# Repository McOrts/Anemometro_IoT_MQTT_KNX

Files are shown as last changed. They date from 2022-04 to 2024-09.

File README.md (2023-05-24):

# Conectividad IoT para anemómetros
Cada día es más habitual el uso de sensores de viento integrados con la lógica domótica de los edificios. Para ello es imprescindible considerar el anemómetro como un dispositivo IoT con capacidad de conexión en los diferentes protocolos de comunicación: MQTT, KNX, y LoRaWAN medios de transmisión de modulación inalámbrica como LoRA e WiFi o cableada con Ethernet con TCP/IP.

## Versión Arduino WEMOS-D1 MQTT por WiFi
Esta es la versión más simple y versátil. El sensor está conectado a un microcontrolador ESP8266 montado en una caja estanca con resistencia IP66 por lo que puede instalarse en el exterior. Además podrá utilizarse como dispositivo portátil.

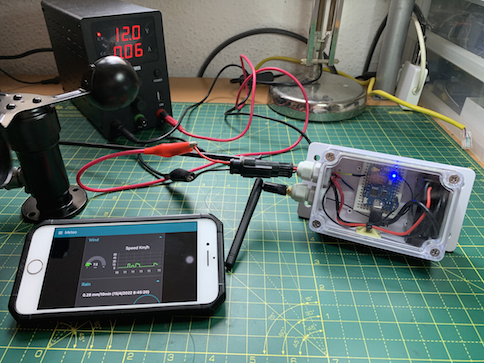
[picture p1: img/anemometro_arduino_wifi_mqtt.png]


### Lista de materiales
- [Anemómetro de cazoletas SKU:SEN0170](https://www.dfrobot.com/search-SEN0170.html)
- [WEMOS D1 Mini Pro 4M](https://es.aliexpress.com/item/32801063577.html)
- [Adaptador de corriente 12V a micro-USB](https://es.aliexpress.com/item/32973455778.html)
- [Caja exterior resistencia IP66 tapa transparente](https://es.aliexpress.com/item/4000200361035.html)

### Montaje
Utilizando cualquier protoboard solo se requiere conectar la masa comùn del microcontrolador y el anemómetro y la senal de tensión de salida del mismo a la entrada analógica del Wemos (ESP8266)

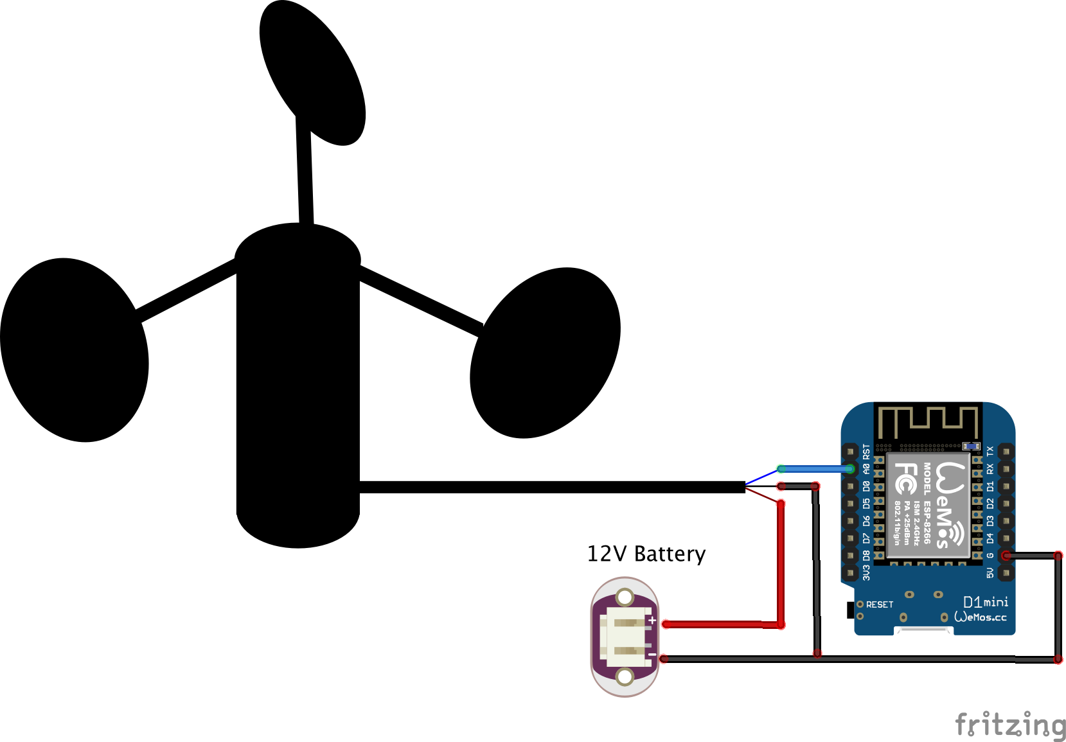
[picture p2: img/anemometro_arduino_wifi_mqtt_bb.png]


### Software
Partimos de que se dispone de un broker MQTT tipo Mosquitto y un Node-RED para procesar la información. El firmware utiliza la librería para WiFi (ESP8266WiFi.h) y la de MQTT (PubSubClient.h).
Como se ha utilizado un anemómetro alimentado por 12V que traduce la velocidad del viento a una tensión de salida entre los 0.17V para una velocidad de 1m/s a 5V para 30 m/s. El programa del microcontrolador hará este cálculo de manera que el mensaJe MQTT contiene unicamente la velocidad del viento.
Además el programa, cuando hay viento, enciende el led de la placa WEMOS Apagándolo cuando es igual a cero.

```cpp
#include <ESP8266WiFi.h>
#include <PubSubClient.h>
#include "settings.h"

unsigned long int temp1;

/* Configuración sensor */
unsigned int WindSpeed ;              

/* Configuración cliente WiFi */
WiFiClient espClient;

/* Configuración MQTT */
PubSubClient clientMqtt(espClient);
char msg[50];
String mqttcommand = String(14);

void setup() {
  Serial.begin(9600);

  // Inicializa el LED de la placa
  pinMode(LED_BUILTIN, OUTPUT);
  digitalWrite(LED_BUILTIN, HIGH);
  delay(500);

  /* Iniciar wifi */
  setup_wifi();
  clientMqtt.setServer(mqtt_server, mqtt_port);
  clientMqtt.setCallback(callback);
}

void setup_wifi() {
  delay(10);

  // Comienza el proceso de conexión a la red WiFi
  Serial.println();
  Serial.print("[WIFI]Conectando a ");
  Serial.println(ssid);

  // Modo estación
  WiFi.mode(WIFI_STA);
  // Inicio WiFi
  WiFi.begin(ssid, password);

  while (WiFi.status() != WL_CONNECTED) {
    delay(500);
    Serial.print(".");
  }

  Serial.println("");
  Serial.println("[WIFI]WiFi conectada");
  Serial.print("[WIFI]IP: ");
  Serial.print(WiFi.localIP());
  Serial.println("");
}

void callback(char* topic, byte* payload, unsigned int length) {
  Serial.print("[MQTT]Mensaje recibido (");
  Serial.print(topic);
  Serial.print(") ");
  mqttcommand = "";
  for (int i = 0; i < length; i++) {
    mqttcommand += (char)payload[i];
  }
  Serial.print(mqttcommand);
  Serial.println();
  // Switch on the LED if an 1 was received as first character
  if (mqttcommand == "comando") {
    Serial.println("comando");
  }  
}

void reconnect() {
  Serial.print("[MQTT]Intentando conectar a servidor MQTT... ");
  // Bucle hasta conseguir conexión
  while (!clientMqtt.connected()) {
    Serial.print(".");
    // Intento de conexión
    if (clientMqtt.connect(mqtt_id)) { // Ojo, para más de un dispositivo cambiar el nombre para evitar conflicto
      Serial.println("");
      Serial.println("[MQTT]Conectado al servidor MQTT");
      // Once connected, publish an announcement...
      clientMqtt.publish(mqtt_sub_topic_healthcheck, "starting");
      // ... and subscribe
      clientMqtt.subscribe(mqtt_sub_topic_operation);
    } else {
      Serial.print("[MQTT]Error, rc=");
      Serial.print(clientMqtt.state());
      Serial.println("[MQTT]Intentando conexión en 5 segundos");

      delay(5000);
    }
  }
}

void loop() {
  if (!clientMqtt.connected()) {
    reconnect();
  }
  clientMqtt.loop();
    
  if (millis()-temp1>update_time_sensors) {
    temp1=millis();
    
    // Lectura del puerto analógico y traducción del voltaje a velocidad  
    WindSpeed = 6 * analogRead(A0) * (5.0 / 1023.0);

    Serial.print("Velocidad del viento: ");
    Serial.print(WindSpeed);
    Serial.println(" m/s");
      
    // Envía la lectura por MQTT
    snprintf (msg, 10, "%6i", WindSpeed);
    Serial.print("[MQTT] Sending data: ");
    Serial.println(msg);
    clientMqtt.publish(mqtt_pub_topic_voltage, msg);   
    delay (1000);
    if (WindSpeed==0) {
      digitalWrite(LED_BUILTIN, HIGH);       
    } else {
      digitalWrite(LED_BUILTIN, LOW);
    }
  }
}
```
Los parámetros de conexión y tiempos, están definidos en un setting.h:

```cpp
// WiFi Configuration
const char* ssid = "MiFibra-2D79-terraza";
const char* password = "";

// MQTT Configuration
const char* mqtt_server = "192.168.1.114";
const int mqtt_port = 1883;
const char* mqtt_id = "anemometer_cups";
const char* mqtt_sub_topic_healthcheck = "/home/meteo/anemometer/healthcheck";
const char* mqtt_pub_topic_voltage = "/home/meteo/anemometer/wind_speed";
const char* mqtt_sub_topic_operation = "/home/meteo/anemometer/operation";

// Other params
const int update_time_sensors = 59000;
```

### Back-end
El procesado y almacenamiento de la información se orquesta desde una aplicación Node-RED. El _flow_ está subscrito al _topic_ de velocidad de viento "/home/meteo/anemometer/wind_speed". A partir del mensaje con la velocidad de viento en m/s, se hace el cálculo a km/h para almacenar el dato en una BBDD MySQL, presentar la información en un _dashboard_ y validar el umbral de alerta para enviar un mensaje por el servicio IFTTT. El código .json del flujo está en: https://github.com/McOrts/Anemometro_IoT_MQTT_KNX/blob/main/code/node-red_flow.json



## Versión RaspberryPi MQTT por Ethernet
También se puede implementar un sensor de viento sobre una _single board computer_ como la Raspberry Pi y utilizando señal de pulsos como la que tiene anemómetros como el [WH-SP-WS01](https://es.aliexpress.com/item/1005001484228267.html)

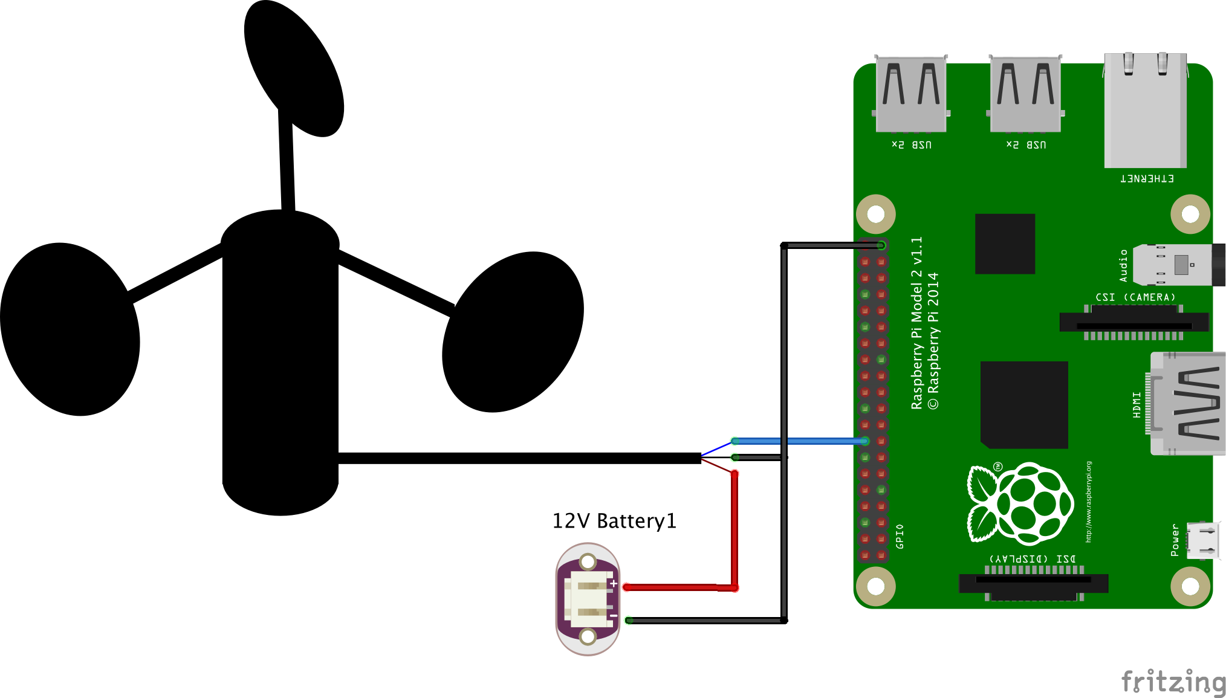
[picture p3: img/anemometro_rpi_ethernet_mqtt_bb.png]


### Sofware
En este caso he empleado un programa Python que además de enviar el mensaje MQTT, almacena la lectura en una BBDD MySQL y notifica por mail si la velocidad del viento excede de un umbral. Este y otro parámetros están configurados externamente en el fichero config.json.

```python
#!/usr/bin/python
# -*- coding: utf-8 -*-

import RPi.GPIO as GPIO
import smtplib
import datetime
import time
import MySQLdb as mdb
import logging
import os
import fnmatch
import math
import json
from pprint import pprint
import sys
import paho.mqtt.client as mqtt

# To avoid the error on rc.local execution envirotment: 
#WARNING urllib3.connectionpool Retrying (Retry(total=2, connect=None, read=None, redirect=None, status=None)) after connection broken by 'NewConnectionError('<urllib3.connection
logging.getLogger("urllib3").setLevel(logging.ERROR)

# Then the code sets up the logging module. We are going to use the basicConfig() function to set up the default handler 
# so that any debug messages are written to the file /home/pi/event_error.log.
logging.basicConfig(filename='/home/pi/wind_event_error.log',
  level=logging.DEBUG,
  format='%(asctime)s %(levelname)s %(name)s %(message)s')
logger=logging.getLogger(__name__)

# Read the configuration file
DEFAULT_CONFIG_PATH = '/home/pi/config.json'
with open(DEFAULT_CONFIG_PATH, 'r') as config_file:
  config = json.load(config_file)

# anemometer parameters
count = 0
radius = 9.0
comp_factor = 2.3
interval = 60
speed = 0

# Function for storing readings into MySQL
def insertDB(speed):
  try:
    con = mdb.connect(config['db_server_ip'],
                      config['db_update_user'],
                      config['db_update_password'],
                      'measurements');
    cursor = con.cursor()
    sql = "INSERT INTO wind(speed) VALUES ('%s')" % (speed)
    cursor.execute(sql)
    sql = []
    con.commit()
    con.close()
  except mdb.Error as e:
    logger.error(e)

# Function for send an email notifing the speed reach the maximum 
def send_email_wind_speed(speed):
    # Specifying the from and to addresses
    toaddr = config['mail']['toaddr']
    cc = config['mail']['cc']
    fromaddr = config['mail']['fromaddr']
    message_subject = "[WIND] Home wind speed alert"
    message_text = "The wind speed is (Km/h): %s" % speed
    message = "From: %s\r\n" % fromaddr + "To: %s\r\n" % toaddr + "Subject: %s\r\n" % message_subject + "\r\n"  + message_text
    toaddrs = [toaddr] 
    username = '¿?@gmail.com'
    password = '¿?'
    # Sending the mail  
    try:
      server = smtplib.SMTP_SSL("smtp.gmail.com", 465)
      server.ehlo()
      server.login(config['mail']['username'],config['mail']['password'])
      # ssl server doesn't support or need tls, so don't call server.starttls() 
      server.sendmail(fromaddr, toaddrs, message)
      server.close()
    except:
      print ("failed to send mail")

# Function for calculate wind speed
def calculate_speed(r_cm, factor, time_sec):
    global count
    circ_cm = (2 * math.pi) * r_cm
    rot = count / 2.0
    dist_km = (circ_cm * rot) / 100000.0 # convert to kilometres
    km_per_sec = dist_km / time_sec
    km_per_hour = km_per_sec * 3600 # convert to distance per hour
    km_per_hour = km_per_hour * factor
    km_per_hour = round(km_per_hour,2)
    return km_per_hour

def spin(channel):
    global count
    count += 1

# Function for publish MQTT messages
def publish_MQTT_messages (p_event):
  try:
    client = mqtt.Client()
    # compose the message 
    topic = config['domohome_wind']['topic']
    payload = '{:3.2f}'.format(p_event / 1.)
    client.connect(config['MQTT']['broker_server_ip'],1883,60)
    client.publish (topic, payload)

    client.disconnect();
  except Exception as e:
    print ("exception")
    logger.error("Exception MQTT sending message: %s\n"+" "+e.__str__())

GPIO.setmode(GPIO.BCM)
GPIO.setup(config['domohome_wind']['gpio_pin'], GPIO.IN, GPIO.PUD_UP)
GPIO.add_event_detect(config['domohome_wind']['gpio_pin'], GPIO.FALLING, callback=spin)

while True:
    count = 0
    time.sleep(interval)
    speed = calculate_speed(radius, comp_factor, interval)
#    insertDB (speed)
    publish_MQTT_messages(speed)
    if speed > config['domohome_wind']['max_warning']:
        send_email_wind_speed(speed) 
```

## Versión Arduino UNO KNX
Otra opción más compleja es la integrar el sensor de viento en un bus KNX. Para asegurar la compatibilidad he usado un Arduino Uno original. El modo de lectura del anemómetro es idéntico al utilizado en el WEMOS D1. Pero la transmisión del mensaje se hace a través de comandos enviados por el puerto serie del Arduino.
A su vez necesitamos traducir estas señales a modo TTL y formato RS323 que es la manera en la que podremos insertar el mensaje en el bus KNX utilizando el gateway SKX-Open de Zennio. 

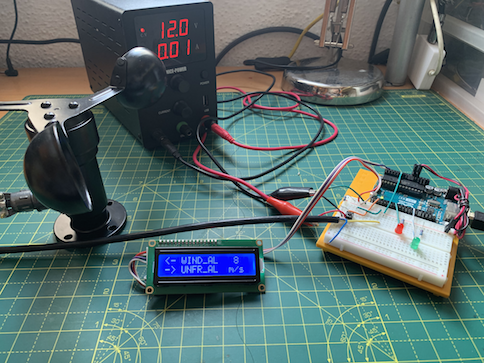
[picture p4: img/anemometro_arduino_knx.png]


### Hardware
Para este montaje, además del anemómetro de referencia utilizado [SKU:SEN0170](https://www.dfrobot.com/search-SEN0170.html), y un Arduino Uno. Para poder llevar el mensaje al bus NKX necesitamos dos componentes:
- [Módulo convertidor de puerto serie MAX3232 RS232 a TTL](https://es.aliexpress.com/item/32982290904.html)
- [Interface Bus KNX a RS232](https://www.zennio.com/products/interfaces/skx-open)

### Montaje

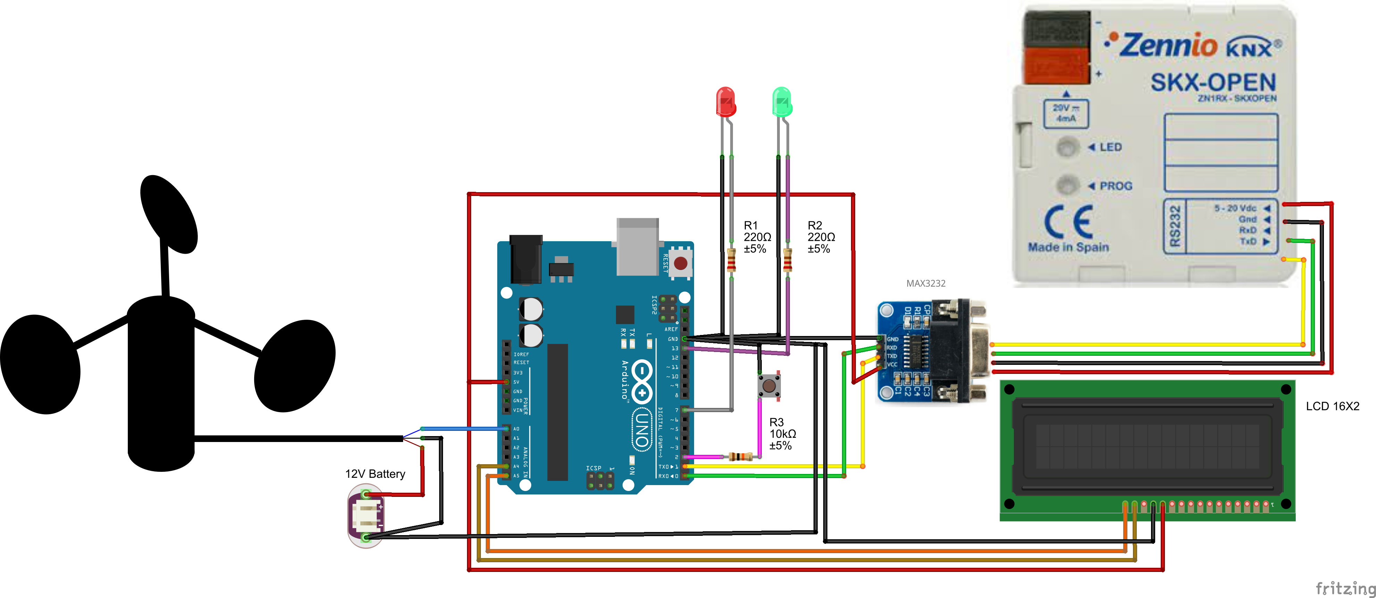
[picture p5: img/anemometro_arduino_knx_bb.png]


### Sofware
En este caso tenemos un sketch de arduino con una lógica más compleja para construir un diálogo a fin de interactuar con los otros elementos de la red KNX como persianas y botoneras.

```cpp
/* Diálogo:
Estado incial: leds apagados y no lee el sensor.
Cuando se pulsa el botón  
(1) Se empieza a leer el sensor cada 2 segundos
  * Si el valor < 800
    * Se envia "NOAL"
  * si el valor >=4 m/s
    * Se envía "WIND_AL" 
    * Se conmuta el LED del verde al rojo
    * Deja de leer el sensor
    * Se espera a recibir un "CLOSED_S" que indica que la persiana está cerrada
    * Se apaga el led rojo
    * Se espera a recibir un "UNFROZEN_AL" indica desbloqueo del usuario desde la botonera KNX
    * Se espera un segundo y
       * Se envia un "UNFR"
       * Se reestablece el estado al punto (1)
*/
#include <Wire.h> 
#include <LiquidCrystal_I2C.h>

#define sensor A0 
#define boton 2 
#define ledrojo 7
#define ledverde 12

const int sensorvalue = 4;

bool leyendo;
unsigned long int temps1;
String incomingString;

//Creamos el objeto lcd con la dirección 0x3F, 16 columnas y 2 filas
LiquidCrystal_I2C lcd(0x3F,16,2);  

void setup() {
  Serial.begin(9600);
  pinMode (sensor, INPUT);
  pinMode (boton, INPUT);
  pinMode (ledrojo, OUTPUT);
  pinMode (ledverde, OUTPUT);
  temps1=millis();
  leyendo = false;
  // Inicializamos la pantalla LCD
  lcd.init();
  lcd.backlight();
  lcd.setCursor(0, 0);
  lcd.print("<-");
  lcd.setCursor(0, 1);
  lcd.print("->          m/s");
}

void analizar_sensor(){
  if (millis()-temps1>2000) {
    float outvoltage = analogRead(sensor) * (5.0 / 1023.0);
    int Level = 6*outvoltage;
    lcd.setCursor(13, 0);
    lcd.print(Level);
    if (Level<sensorvalue) {
      Serial.println("NOAL");
      lcd.setCursor(3, 0);
      lcd.print("NOAL    ");
      temps1=millis();
    } else {
      Serial.println("WIND_AL");
      lcd.setCursor(3, 0);
      lcd.print("WIND_AL ");
      digitalWrite(ledverde, LOW);
      digitalWrite(ledrojo, HIGH);
      leyendo = false;
    }
  }
}

void lee_serial(){
  while(Serial.available()) {
//  if (Serial.read()!=-1) {
      incomingString = Serial.readStringUntil('\n');// read the incoming data as string
      if (incomingString=="CLOSED_S") {
        lcd.setCursor(3, 1);
        lcd.print("CLOSED_S ");
        digitalWrite(ledrojo, LOW);
      } else if (incomingString=="UNFR_AL") {
        lcd.setCursor(3, 1);
        lcd.print("UNFR_AL  ");
        delay (1000);
        Serial.println("UNFR");
        lcd.setCursor(3, 0);
        lcd.print("UNFR      ");
        leyendo = true;        
        digitalWrite(ledverde, HIGH);
      }
  }
}

void loop() {
  if (digitalRead(boton)==HIGH) {
    delay (250);
    leyendo = true;
    digitalWrite(ledverde, HIGH);
    digitalWrite(ledrojo, LOW);
  }
  if (leyendo) {
    analizar_sensor();
  }
   
  lee_serial();
}
```

De la parte de KNX, necesitaremos configurar el SKX-Open. En primer lugar, parametrizando el gateway con objetos de 1 bit que mmanejan las tramas que genera y escucha Arduino. En esta configuración las tramas se traducen a sus valores ASCII hexadecimales.

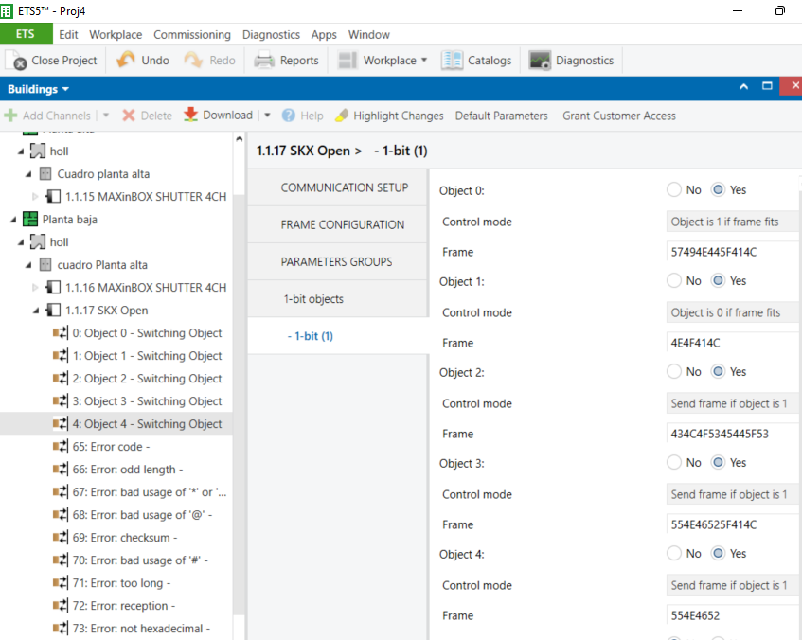
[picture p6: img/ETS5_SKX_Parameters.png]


Finalmente queda construir los grupos y asignar los objetos anteriores en función de lo que queramos hacer con los eventos. En este caso cerrar persianas y desenclavar sis objetos de alarma.

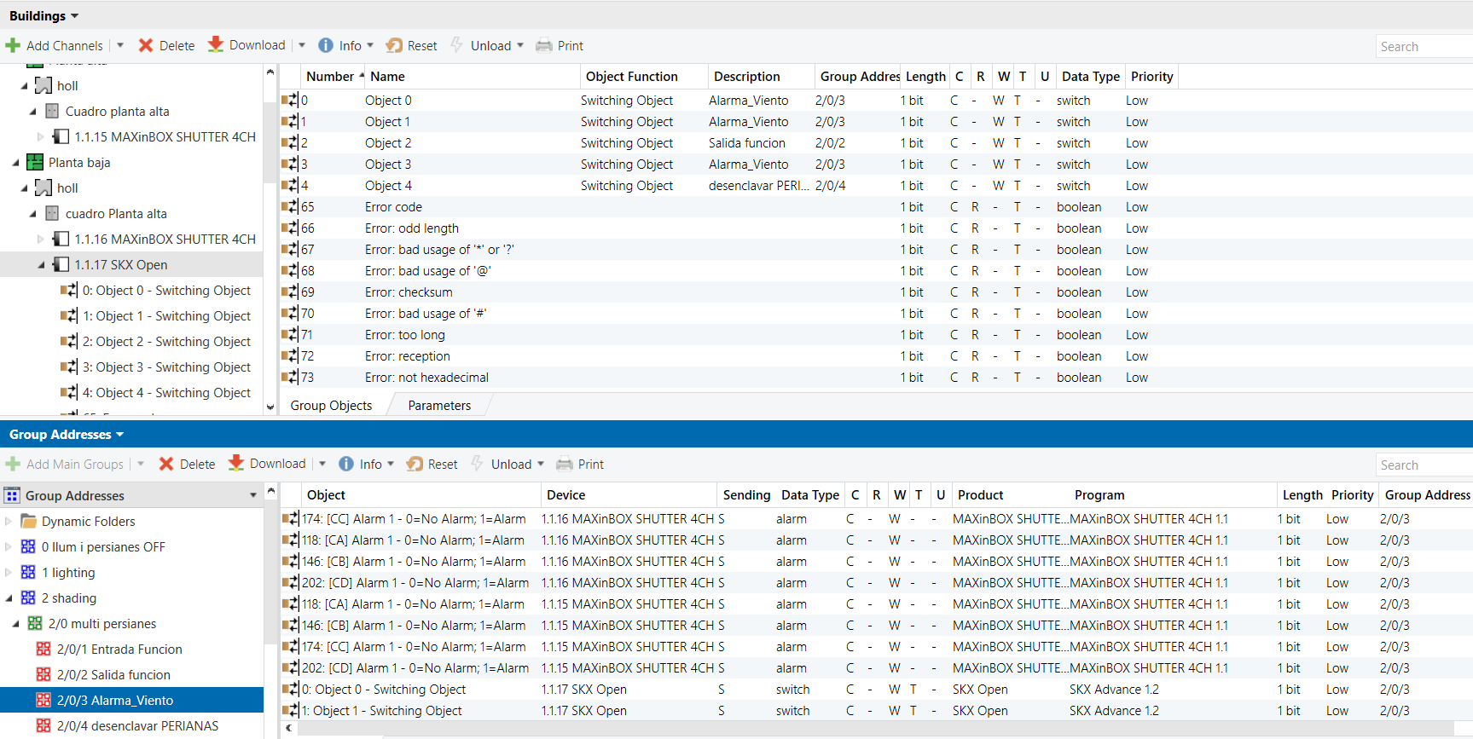
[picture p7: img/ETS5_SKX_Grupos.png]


## Versión de LoRaWAN con TTN

### Montaje

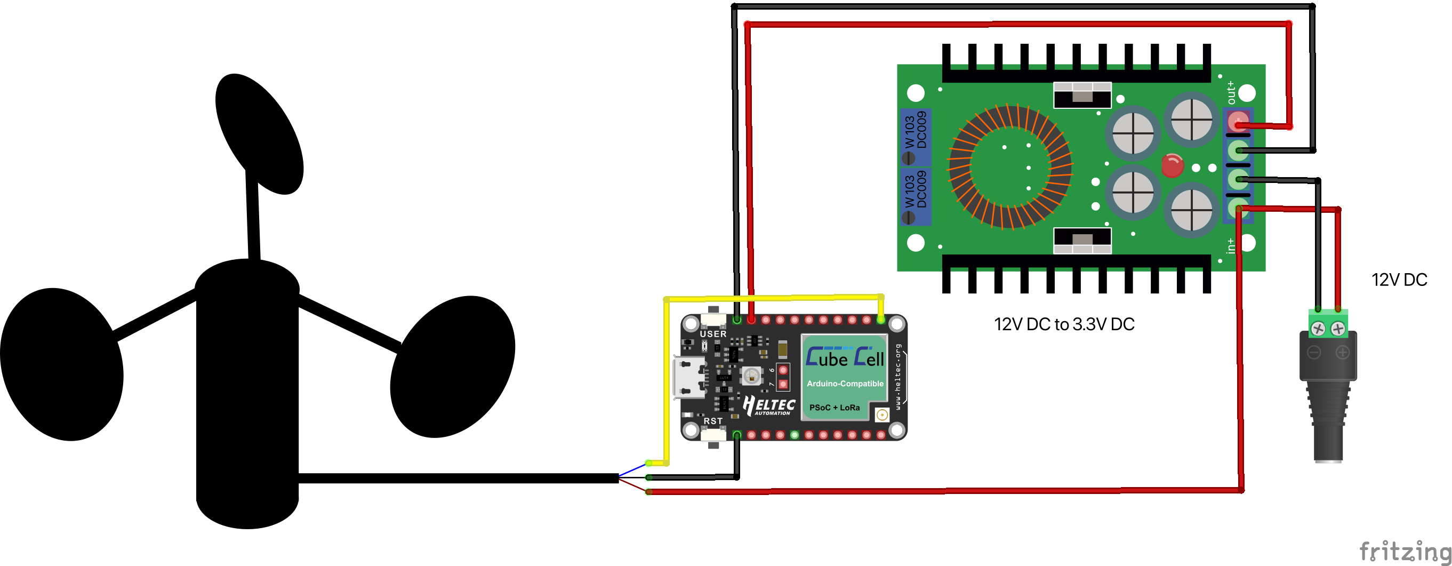
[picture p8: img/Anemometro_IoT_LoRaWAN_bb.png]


### Configuración IDE Arduino
Lo para poder programar adecuadamente el dispositivo tendremos que configurar el entorno de programación de Arduino con las configuraciones de hardware y librerías de esta placa.
1. Añadir la URL https://github.com/HelTecAutomation/CubeCell-Arduino/releases/download/V1.5.0/package_CubeCell_index.json a Preferences->Settings->Additional boards:
2. Añadir la librería de CayenneLPP. **Importante: versión 1.1.0**:

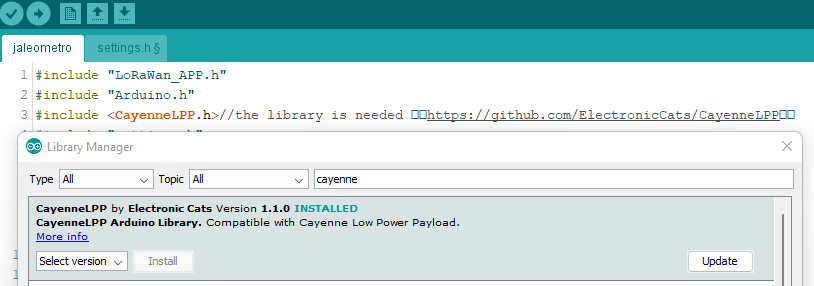
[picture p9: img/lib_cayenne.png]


3. Si aparece un aviso de instalar otras librerias con dependencias. Seleccionar opción de instalar todas:

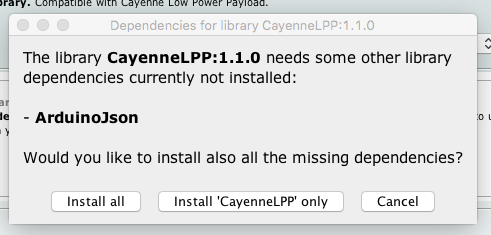
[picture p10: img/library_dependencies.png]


4. Seleccionar la tarjeta CubeCell HTCC-AB01 y configurar todos sus parámetros así:

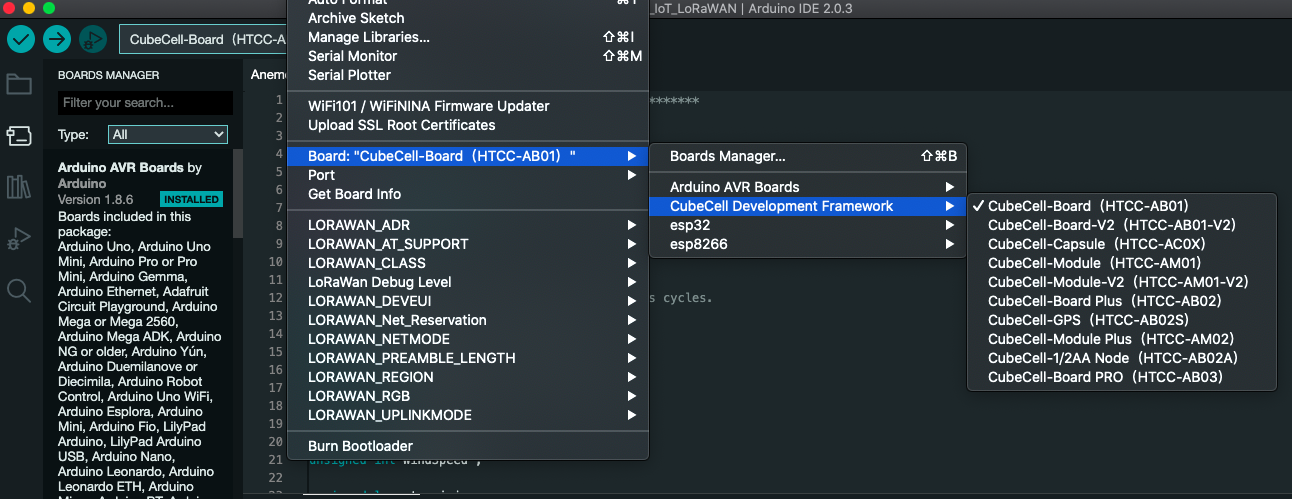
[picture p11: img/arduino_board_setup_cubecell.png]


### Subir el sketch de Arduino
Con el cable conectado seleccionamos el puerto USB que nuestro ordenador haya asignado. Una vez compilado y cargado en el dispositivo. Abrimos el monitor serie para comprobar que log de actividad del programa es correcto.

### Configuración del sensor en la nube (TTN)

Vamos a utilizar los servicios de The Things Network que es un servicio en la nube al que están conectados los _gateway_ libres de la las Comunidades TTN. 
La ruta de la información es la siguiente:
1. El sensor (_nodo_) transmite por radio con modulación LoRa el trama de datos que recibe el _gateway_
2. Este _gateway_ está conectado a internet para retransmitir la trama, hora como paquete de datos.
3. Los servidores de TTN decodifican el mensaje y ofrecen diferentes integraciones y _endpoints_ para que nuestras aplicaciones utilicen la información leída por los sensores.

Hay muchas variantes para implementar este enrutamiento. Para este se ha elegido estas configuraciones:
- Dispositivo es del tipo OTAA (Over-The-Air Activation) un dispositivo final realiza un procedimiento de identificación con una red LoRaWAN, durante el cual se asigna una _DevAddr_ dinámica a un dispositivo final y las claves raíz se utilizan para derivar claves de sesión. Por lo tanto, _DevAddr_ y las claves de sesión cambian a medida que se establece cada nueva sesión.
- Publicación del paquete de-codificado en una cola MQTT a la que nuestra aplicación está subscrita.

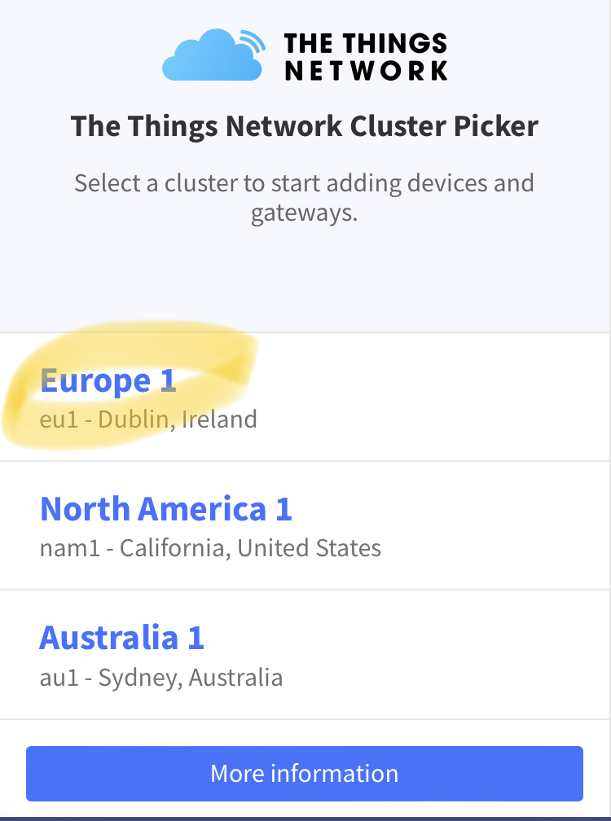
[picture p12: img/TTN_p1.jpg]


Estos son los pasos a seguir empezando por acceder a la aplicación _back-end_ de TTN en esta URL: https://console.cloud.thethings.network/ en la que seleccionaremos nuestra región y luego nos loguearemos con nuestro usuario registrado.

<br>
<br>
<br>
<br>
<br>
<br>
<br>

### Registro de la aplicación
En TTN los dispositivos (_devices_) iguales, se agrupan en una aplicación desde la cual serán registrados. por lo tanto, primero hay que añadir una aplicación:

En el formulario de alta de aplicación rellenaremos estos campos: 
- Para el _Application ID_, elige un identificador único, en minúsculas, puedes usar caracteres alfanuméricos peor no guiones ´-´ consecutivos.
- Para  _Description_, elige la descripción que prefieras.
- No hace falta poner nada en _Application EUI_ 
- Presiona _Create application_ para finalizar

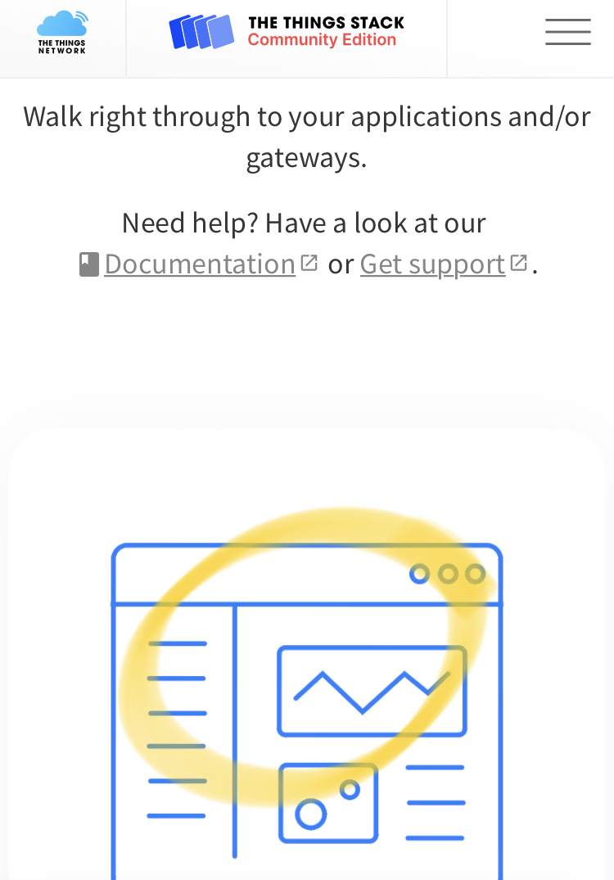
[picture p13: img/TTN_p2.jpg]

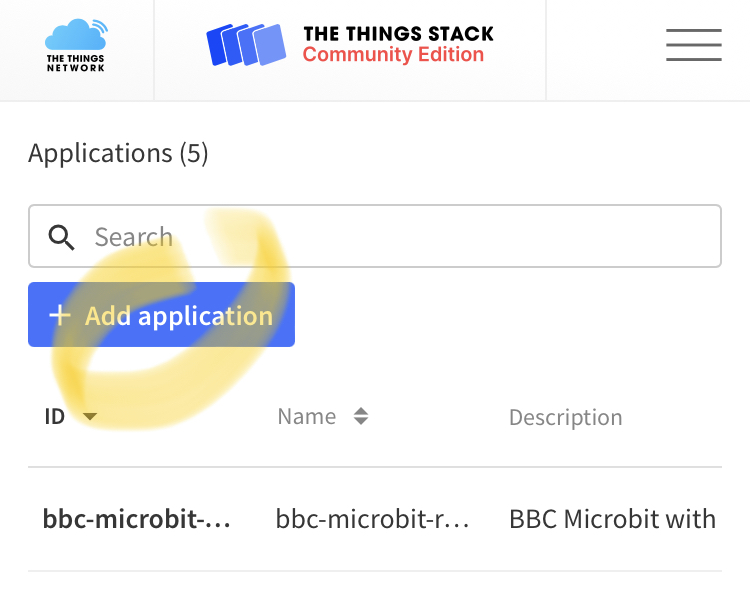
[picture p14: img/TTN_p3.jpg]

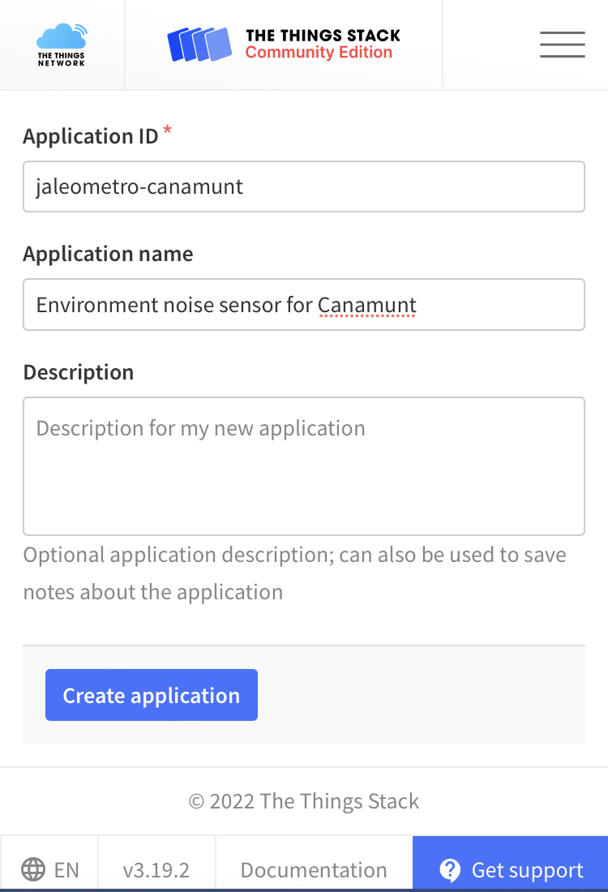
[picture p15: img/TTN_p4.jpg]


<br>
<br>
<br>
<br>
<br>
<br>
<br>
<br>

Aparecerá ahora la página con la nueva aplicación añadida donde encontrarás un botón de _+ Add end device_ necesario para crear los dispositivos asociados. 

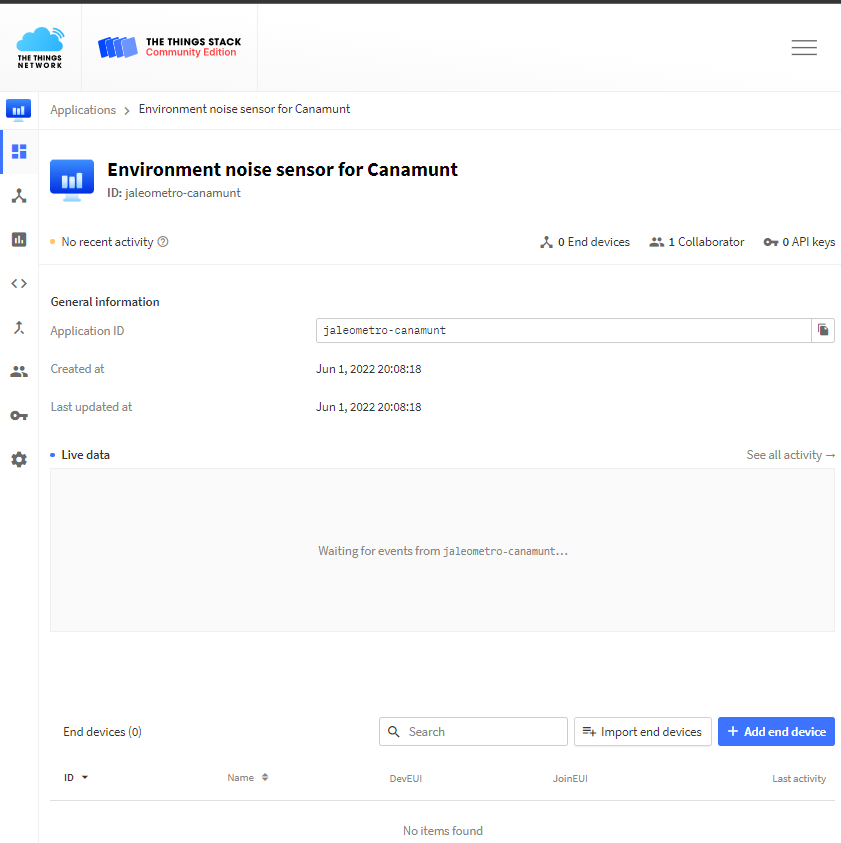
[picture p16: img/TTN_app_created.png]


### Registro del dispositivo
En TTN un dispositivo (devide) representa la configuración de lo que también llama nodo (node) que a fin de cuentas es nuestro sensor. 
Al acceder al formulario de registro nos quedamos en la pestaña de _From The LoRaWAN Device Repository_ ya que estamos usando un microcontrolador conocido.
Ahora tenemos que seleccionar el tipo, modelo y marca de nuestro sensor tal y como aparece en la captura inferior. 
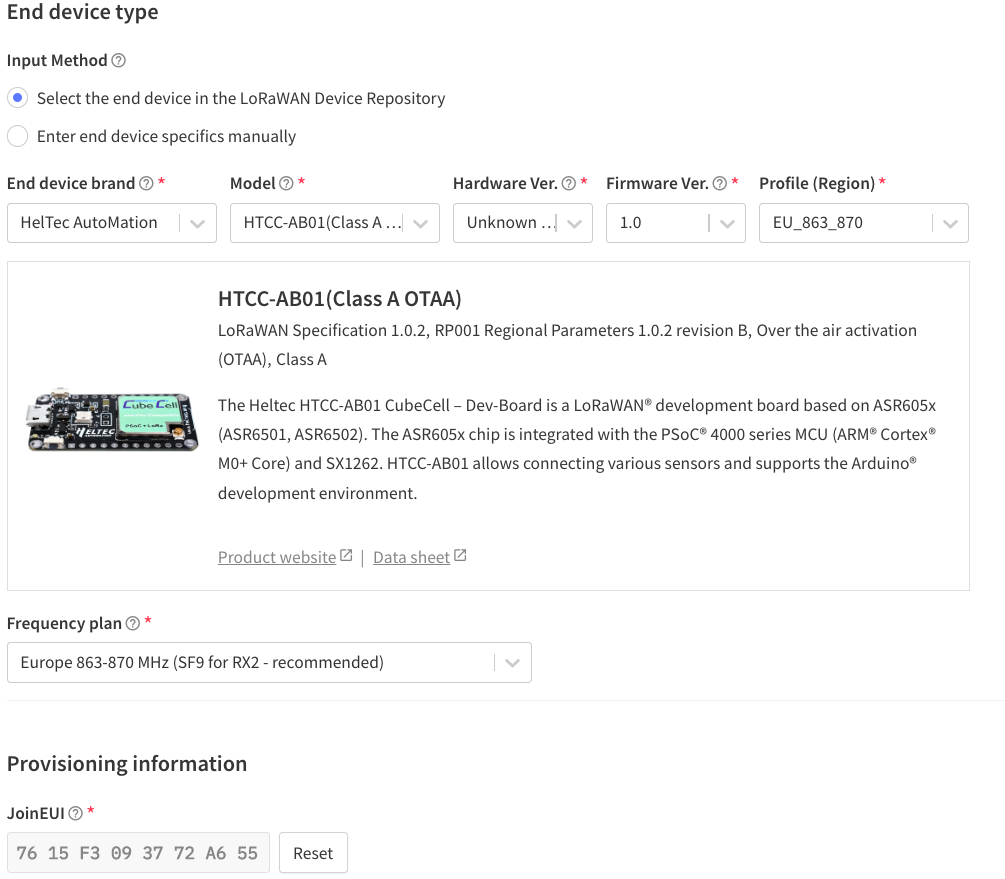
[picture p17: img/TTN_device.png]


El la casilla inferior vemos que pide una clave de JoinEUI que normalmente nos la daría el fabricante. Pero en nuestro caso utilizaremos una sencilla aplicación web para generarla:  https://descartes.co.uk/CreateEUIKey.html
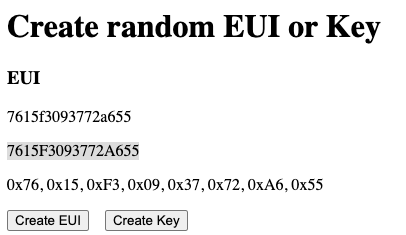
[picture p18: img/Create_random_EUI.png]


Lo siguiente será generar las _DevEUI_ y _AppKey_ pulsando los correspondientes iconos de la derecha para que se genere automáticamente.
Finalmente queda rellenar el _Device ID_ que será el nombre único de este nodo.

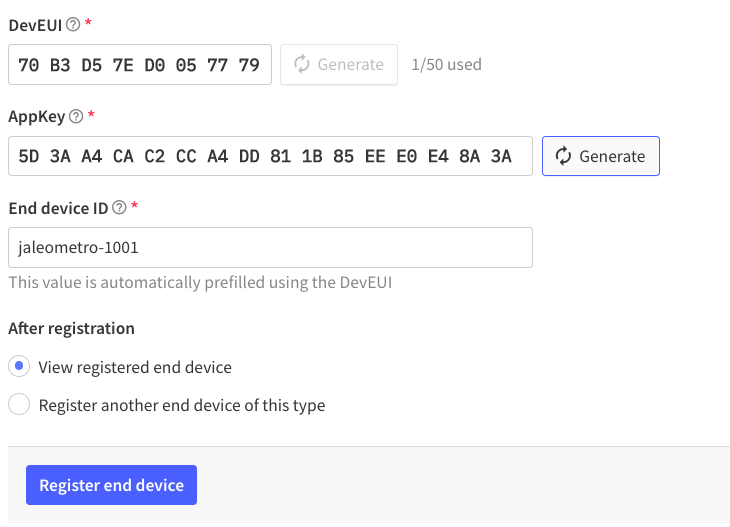
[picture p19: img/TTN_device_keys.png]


Finalmente pulsaremos _Register en device_ para que, seguidamente aparezca la pantalla con la configuración de nuestro nuevo nodo.Aquí podremos ver los datos de configuración y parámetros que necesitamos por ser un dispositivo de tipo ABP. Y que tendremos que pasar al fichero de configuración settings.h que se cargará en el _sketch_ del IDE de Arduino.

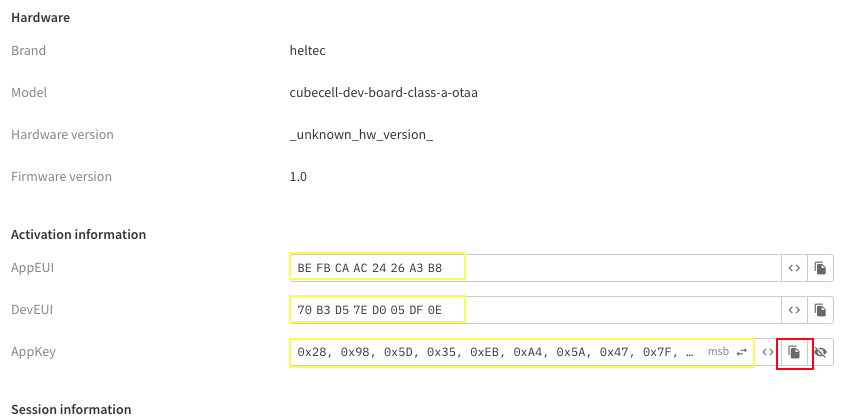
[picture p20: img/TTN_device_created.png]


Para poder copiar las _keys_ en el formato "array" que se requiere en el fichero de configuración: "settings.h" 
Nota: hay que pulsar el icono <> de "_toggle array formating_" para tener el formato adecuado para este fichero.

```cpp
// LoRaWAN Configuration

/* OTAA para*/
static uint8_t devEui[] = {  };
static uint8_t appEui[] = {  };
static uint8_t appKey[] = {  };

uint16_t userChannelsMask[6]={ 0x00FF,0x0000,0x0000,0x0000,0x0000,0x0000 };
static DeviceClass_t lorawanClass = LORAWAN_CLASS;

// Devise location
const float latitude = 39.573;
const float longitude = 2.732;
const int alt = 20;

// Other params
float SensorId= 10.01;// Sensor  identifcator number 
const int DutyCycle = 600000; // Transmision and reading period
const int Sleep4NoNoise = 300000; // Sleep period when low noise 
const int LowNoiseLevel = 180; // Limit for low noise mode
```

### Formato de la trama

Desde el menú vertical izquierdo accederemos al _Payload Formatters_ y la opción Uplink para definir cómo decodificar la trama de datos de nuestro mensaje LoRa que hemos establecido en el firmware. En nuestro caso hemos usado la librería CayenneLPP y esto es lo que aquí tenemos de seleccionar como tipo:

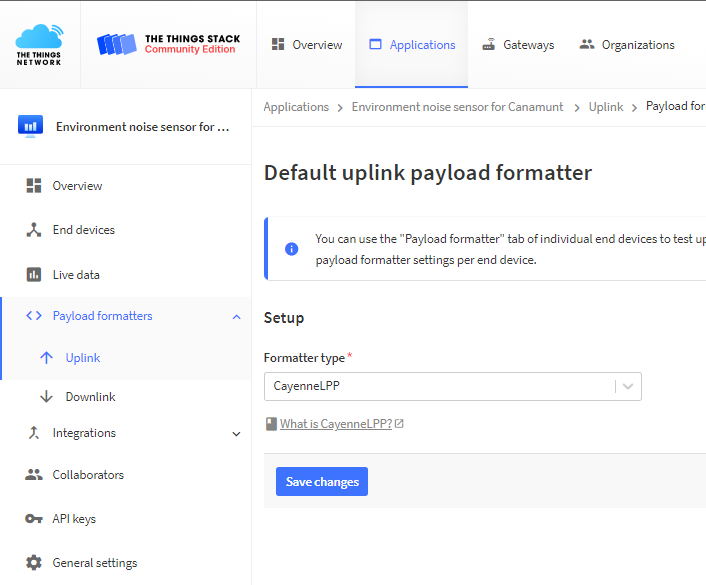
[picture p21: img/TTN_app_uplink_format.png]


De esta manera el mensaje MQTT que vamos a utilizar para leer los valores del sensor; será generado por backend de TTN en una estructura JSON perfectamente formateada:

```json
{
 "uplink_message":{
      "f_port":2,
      "f_cnt":539,
      "frm_payload":"AQID6QFlAE8CZQDDAogGCGAAaiwAC7g=",
      "decoded_payload":{
         "analog_in_1":10.02,
         "gps_2":{
            "altitude":30,
            "latitude":39.936,
            "longitude":3.718
         },
         "luminosity_1":79,
         "luminosity_2":195
      }
}
```
### Integración MQTT
Por último necesitaremos las credenciales de acceso al broker MQTT que TTN nos ofrece como una opción de integración para poder suscribirnos a topic desde nuestra aplicación:

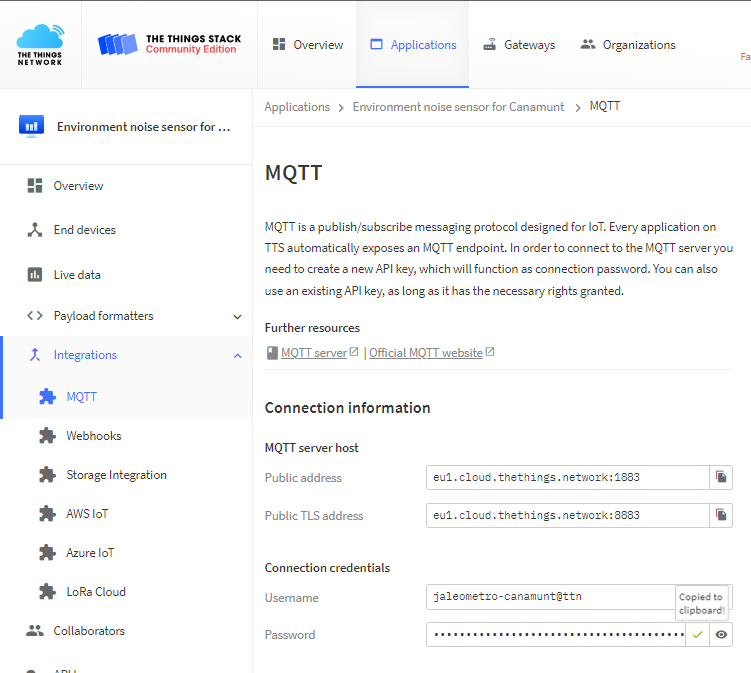
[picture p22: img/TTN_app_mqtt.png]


**IMPORTANTE**: copia el password ahora porque una vez cerrada esta ventana. No tendrás opción a consultarlo.

## Agradecimientos
- **Joaquin González Torres**. Compañero Técnico de Telecomunicaciones
- **Joan Carbonell**. Profesor del IES Politecnic



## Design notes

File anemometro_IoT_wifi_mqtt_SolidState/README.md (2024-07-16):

# 🌬️Anemómetro IoT de estado sólido. Conexión Wifi + MQTT 💨

Cada día es más habitual el uso de sensores de viento integrados con la lógica domótica de los edificios. Para ello es imprescindible considerar el anemómetro como un dispositivo IoT con capacidad de conexión en los diferentes protocolos de comunicación: MQTT, KNX, y LoRaWAN medios de transmisión de modulación inalámbrica como LoRA e WiFi o cableada con Ethernet con TCP/IP.

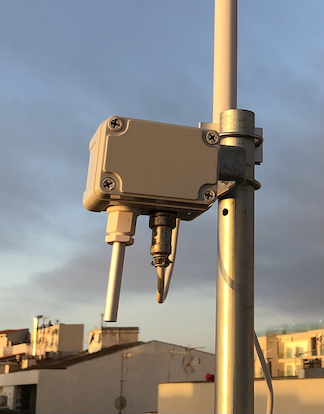
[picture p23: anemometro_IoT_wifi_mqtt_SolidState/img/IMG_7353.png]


## Sin piezas móviles
Existe una versión simple y versátil de anemómetro que puede exponerse en el exterior pudiendo resistir condiciones metereológicas muy adversas. Partimos del sensor de viento modelo SA01 que tiene conectividad serie. El sensor está conectado a un microcontrolador ESP8266 montado en una caja estanca con resistencia IP67 por lo que puede instalarse en el exterior. La alimentación puede hacerse a través de un adaptador de 5V con conector microUSB o con batería directamente conectada a los pines GRN y 5V convirtiéndolo en un dispositivo portátil.

Debido al tipo de tecnología que utiliza este dispositivo. También tendremos una medición de la temperatura ambiental. 

### Lista de materiales
- [Anemómetro estado sólido SA01 de ECDSL](https://www.ecdsl.com/winqx.html)
- [Adaptador caja para SA01 de ECDSL](https://www.ecdsl.com/winqx.html)
- [WEMOS D1 Mini Pro 4M](https://es.aliexpress.com/item/32801063577.html)
- [Caja exterior resistencia IP67 de 95x65x55mm](https://es.aliexpress.com/item/4000287507400.html)

| Anemómetro SA01 | Adaptador SA01 | WEMOS D1 Mini PRO| Caja |
|---|---|---|---|
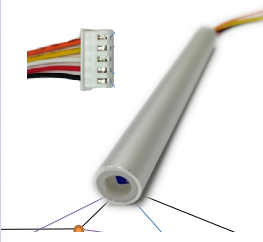
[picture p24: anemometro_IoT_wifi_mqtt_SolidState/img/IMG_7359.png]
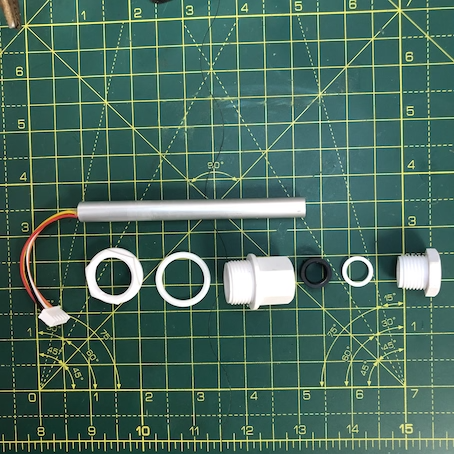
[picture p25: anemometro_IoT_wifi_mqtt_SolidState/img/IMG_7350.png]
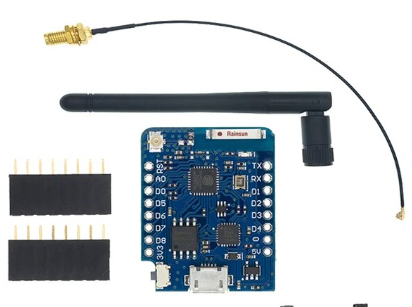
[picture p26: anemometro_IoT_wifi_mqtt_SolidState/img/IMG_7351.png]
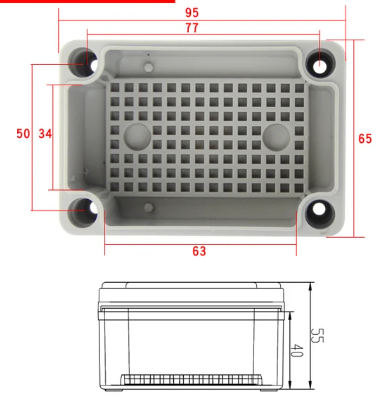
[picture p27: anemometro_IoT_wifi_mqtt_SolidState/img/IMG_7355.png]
|  |  |   |  |

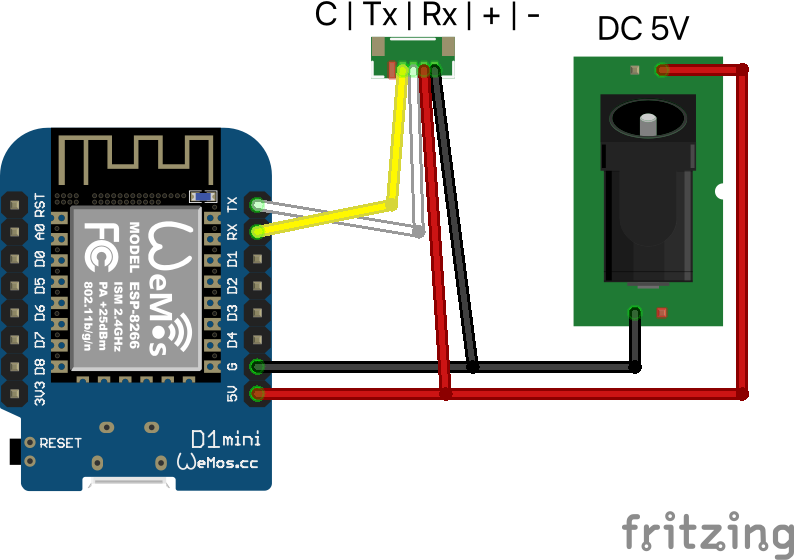
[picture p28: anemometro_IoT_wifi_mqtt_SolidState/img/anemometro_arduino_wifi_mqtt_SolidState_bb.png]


### Montaje
Utilizando cualquier protoboard solo se requiere conectar la masa comùn del microcontrolador, patilla G tanto a la alimentación como al anemómetro. De igual manera conectaremos la entrada de alimentación de 5V al anemóetro y a la primera patilla, la de 5V del microcontrolador. Recibiremos las lecturas por el puerto de transmisión/recepción serie en las respectivas patillas RX y RT del mismo lado del controlador.

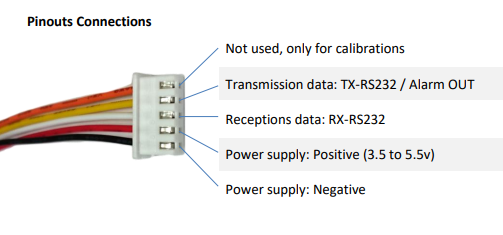
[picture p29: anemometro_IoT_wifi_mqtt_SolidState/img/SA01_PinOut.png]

Teniendo en cuenta las salidas del anemómetro SA01:
<br>
<br>
<br>
<br>
<br>
<br>

Podremos cablear una protoboard como en este ejemplo (los colores coinciden con el esquemático):
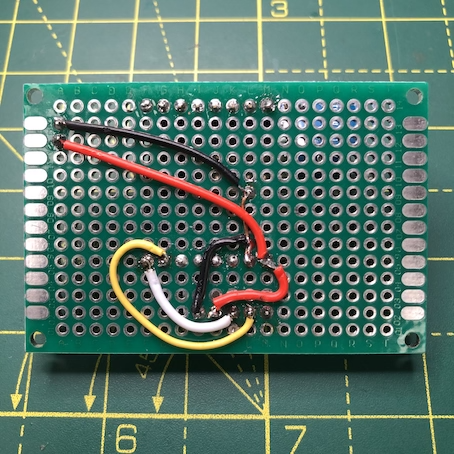
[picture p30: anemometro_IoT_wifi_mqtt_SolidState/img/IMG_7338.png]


Vistas del montaje final. No se incluye la fuente de alimentación de 5V y los conectores para proporcionar esta alimentación a la caja:

| Disposición superior | Montaje en caja | Conectado |
|---|---|---|
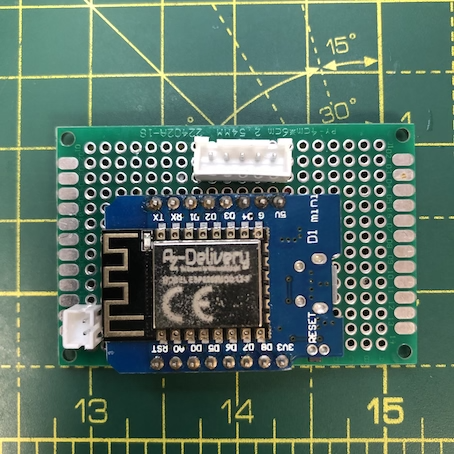
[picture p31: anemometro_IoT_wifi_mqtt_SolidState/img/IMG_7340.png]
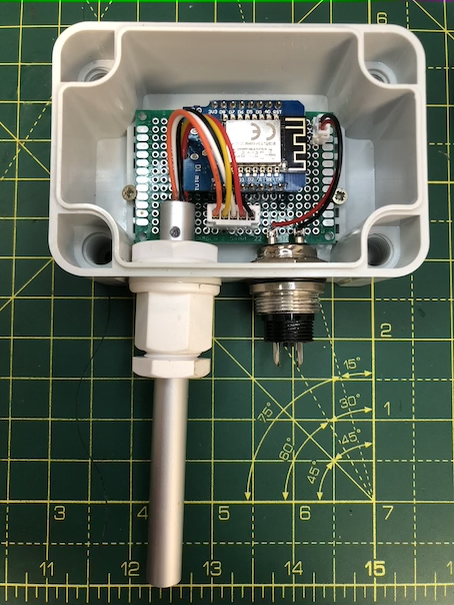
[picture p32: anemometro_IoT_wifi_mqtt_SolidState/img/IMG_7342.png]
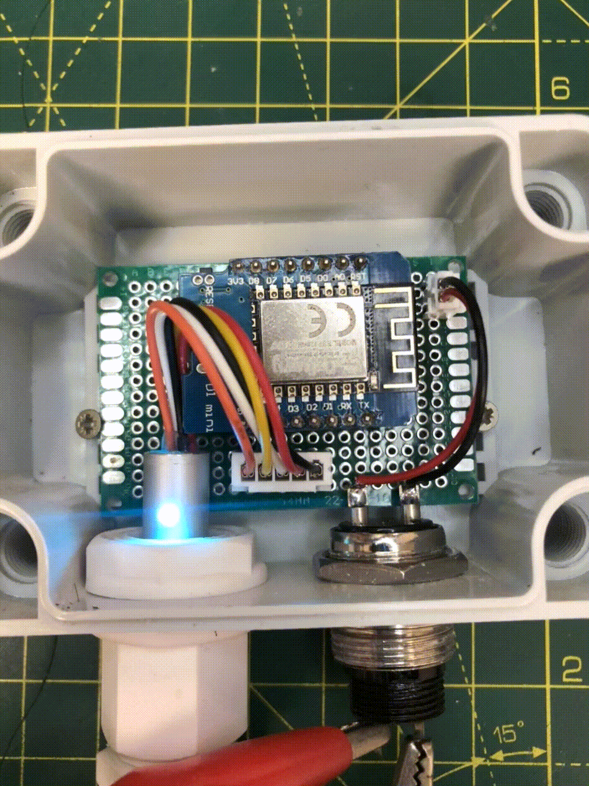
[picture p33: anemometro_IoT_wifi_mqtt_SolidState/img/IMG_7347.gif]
||||

### Software
Partimos de que se dispone de un **broker MQTT** tipo Mosquitto y un Node-RED para procesar la información. El firmware utiliza la librería para WiFi (ESP8266WiFi.h) y la de MQTT (PubSubClient.h).

En primer lugar la aplicación intentará que el WEMOS D1 se conecte a una red Wifi y después al bloker MQTT. Si todo ha sido correcto. Publicará un "staring" en el topic de 'operation', codigo postal grabado en el topic 'cp' y su IP en la red a través del topic 'ip'.

**Las lecturas del viento se leen por el puerto serie cada 15sg**. Pero no se transmiten hasta finalizado el periodo en milisegundos configurado en el fichero setting.h con el parámetro update_time_sensors. Durante este tiempo se calculará el valor medio que será enviado como velocidad del viento y se registrán el máximo y el mínimo.

Además el programa, cuando hay viento, encienderá el led de la placa WEMOS Apagándolo cuando es igual a cero.

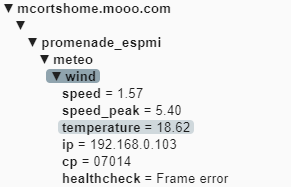
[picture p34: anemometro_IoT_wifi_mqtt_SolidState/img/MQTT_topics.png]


Con este ejemplo, el dispositivo va a publicar la siguiente información en los correspondientes topics:
* Velocidad del viento (mqtt_pub_topic_windspeed)
* Velocidad máxima, dentro de los 15 sg de muestreo (mqtt_pub_topic_windspeedpeak)
* Velocidad mínimna, dentro de los 15 sg de muestreo (mqtt_pub_topic_windspeedmin)
* Temperatura (mqtt_pub_topic_windtemperature)

Adicionalmente se van a publicar
* Mensaje de estado: "starting" cuando el microcontrolador arranque y "Frame error" en el caso de que la trama del SA01 no se interprete correctamente (mqtt_sub_topic_healthcheck)
* IP de red asignada por el servidor SMTO (mqtt_sub_topic_ip)
* Cópigo postal grabado en el fichero settings.h (mqtt_sub_topic_cp)

Y también se subscribirá a este topic:
* Mesajes de control para acciones o cambiar configuración (mqtt_sub_topic_operation)

Todos estos parámetros están registrados como constantes en el fichero settings.h:
```cpp
// WiFi Configuration
const char* ssid = "";
const char* password = "";

// MQTT Configuration
const char* mqtt_server = "";
const int   mqtt_port = 1188;
const char* mqttUser = "";
const char* mqttPassword = "";
const char* mqtt_id = "anemometer_solid_1";
const char* mqtt_sub_topic_healthcheck = "/promenade_espmi/meteo/wind/healthcheck";
const char* mqtt_sub_topic_operation = "/promenade_espmi/meteo/wind/operation";
const char* mqtt_sub_topic_ip = "/promenade_espmi/meteo/wind/ip";
const char* mqtt_sub_topic_cp = "/promenade_espmi/meteo/wind/cp";

const char* mqtt_pub_topic_windspeed = "/promenade_espmi/meteo/wind/speed";
const char* mqtt_pub_topic_windspeedpeak = "/promenade_espmi/meteo/wind/speed_peak";
const char* mqtt_pub_topic_windspeedmin = "/promenade_espmi/meteo/windspeed_min";
const char* mqtt_pub_topic_windtemperature = "/promenade_espmi/meteo/wind/temperature";

// Other params
const int update_time_sensors = 59000;
```
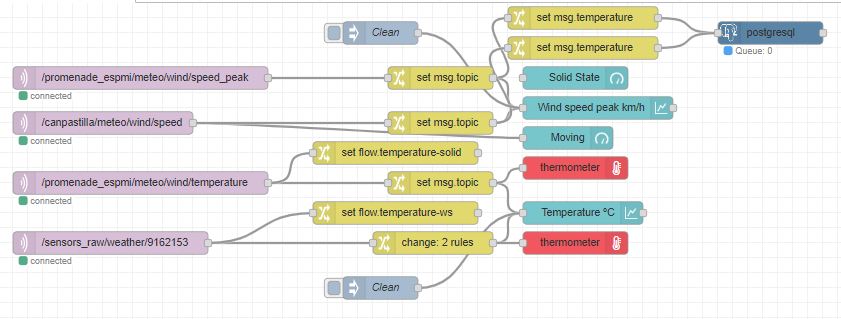
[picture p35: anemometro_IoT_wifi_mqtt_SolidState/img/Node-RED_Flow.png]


### Back-end
El procesado y almacenamiento de la información se orquesta desde una aplicación Node-RED. El _flow_ está subscrito a los _topics_ como el de velocidad de viento "/home/meteo/anemometer/wind_speed". Estos valores se grafican usando nodos de 'dashboard ui' y se persisten en una BBDD PostgreSQL.

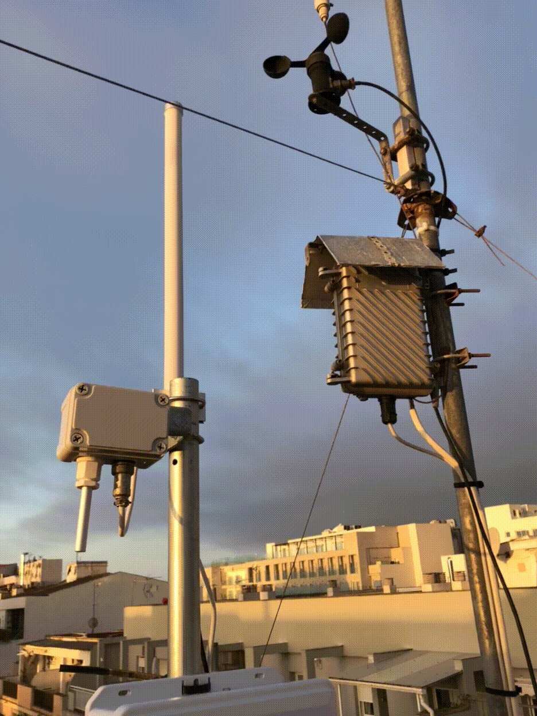
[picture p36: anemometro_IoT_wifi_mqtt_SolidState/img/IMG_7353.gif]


En el ejemplo también se ha utilizado un anemómetro tradicional a efectos de hacer una comparativa entre sus mediciones. Ambos dispositivos se leen a través de mensajes MQTT.

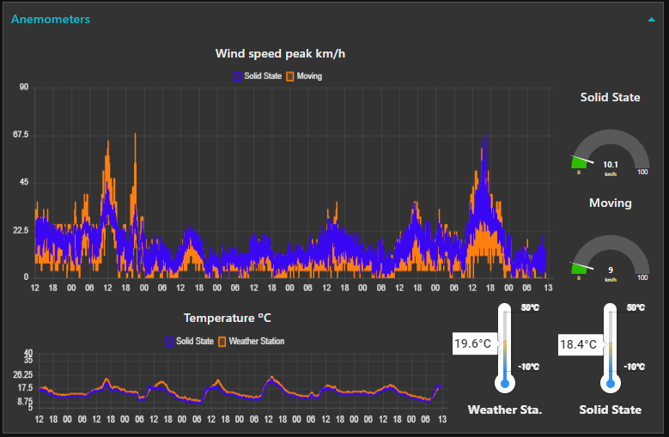
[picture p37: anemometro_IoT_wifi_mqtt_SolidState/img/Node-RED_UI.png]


El código .json de este flujo está en: 
https://github.com/McOrts/Anemometro_IoT_MQTT_KNX/blob/main/anemometro_arduino_wifi_mqtt_SolidState/src/Node-RED_Flow.json

## Agradecimientos
- **Adrian Bracolino**. Creador del dispositivo SA01.
- **Associación de vecinos del Paseig Maritim**. Por permitirnos instalar un protitipo en la terraza de uno de los edificios más altos de la zona

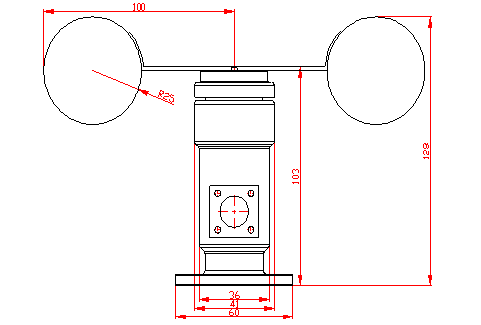
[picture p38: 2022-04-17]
img/schematic_SEN0170.png

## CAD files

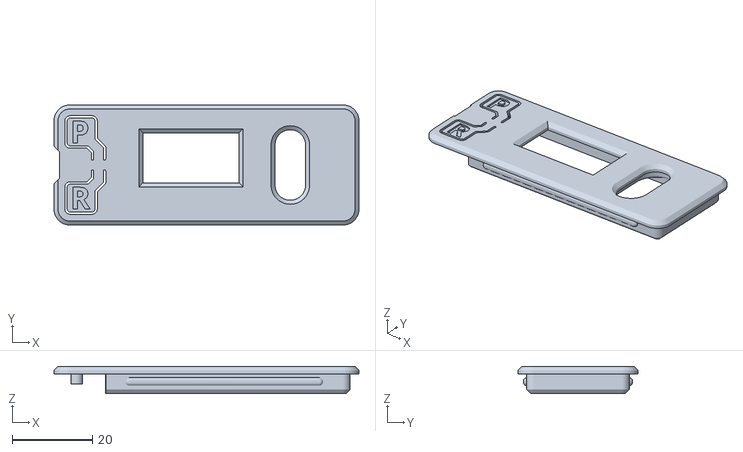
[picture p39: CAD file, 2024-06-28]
anemometro_IoT_LoRaWAN_SolidState/3D/Top.stl
76.2 x 30.0 x 6.79

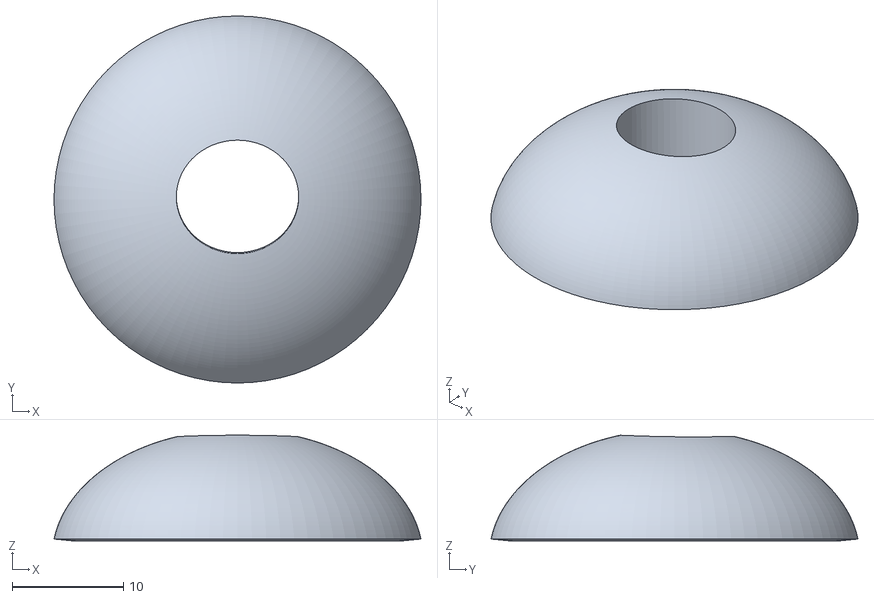
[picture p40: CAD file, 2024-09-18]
anemometro_IoT_wifi_mqtt_SolidState/3D/Paraguas_Anemómetro.stl
33.0 x 33.0 x 9.50

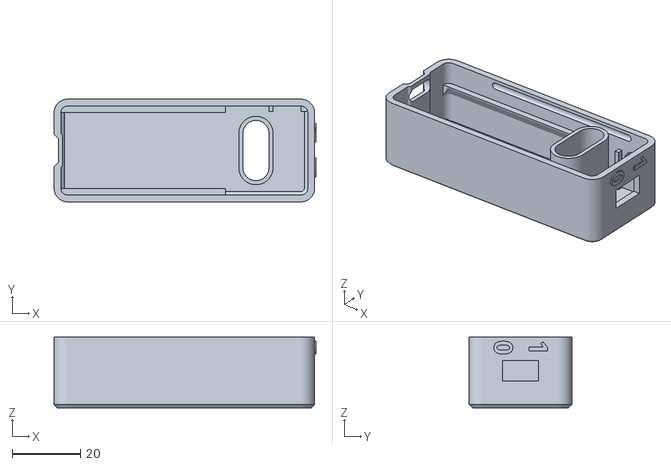
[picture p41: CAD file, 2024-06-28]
anemometro_IoT_LoRaWAN_SolidState/3D/Bottom.stl
76.5 x 30.0 x 20.7

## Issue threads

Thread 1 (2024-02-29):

Consulta alternativa anemómetro

petitxef, 2024-02-29:
Hola!
Primero de todo muchas gracias y felicidades per este súper manual, muy útil!

Me gustaría preguntarte por otra aternativa de anemómetro que pones en tu guía.  Utilizando una ESP32 que tengo por aquí.
Estoy pensando en comprarme este otro (más económico):
https://a.aliexpress.com/_EGZE9CD
Per veo que tiene 4 cables.
Serviría lo mismo?

También quiero enchufarlo a la corriente (220v), y poner un par de convertidores. El diagrama sería así?
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

Muchas gracias!!

McOrts, 2024-03-01:
Hola.
El anemómetro que mencionas parece tener buenas características. Pero, justo el modelo que has seleccionado no sirve porque tiene conectividad RS485. Deberías seleccionar el que tiene salida 0-5V. Y así podrías leer la velocidad directamente con la entrada del conversor AD del microcontrolador.

Tampoco puedes alimentarlo con 220V AC. Seguro que lo quemarías. Según las especificaciones de los cables de conexión es:

Marrón: fuente de alimentación positiva (10V-30V)
Negro: fuente de alimentación negativa
Verde: 485-A
Azul: 485-B
FS-M01:

Gracias por tu interés.

petitxef, 2024-03-01:
Gracias Carlos!
Si, el modelo que me refería es el 0-5v.

Sobre la toma a 220v, tenía pensado poner 2 convertidores, uno de 220v a 5v micro usb (para el ESP32) y otro de 220v a 12v (para el anemómetro).

Que diferencia hay entre los cables 485A y 485B? El que tendría que conectar al microcontrolador es el A o el B?

Muchas gracias!

petitxef, 2024-03-08:
Hola Carlos,
Comentarte que he creado con la base de tu codigo, una version para ESP32 y añadiendo un sensor BME280 a ella.

Te adjunto los codigos:
```

#include <WiFi.h>
#include <PubSubClient.h>
#include <Wire.h>
#include <Adafruit_Sensor.h>
#include <Adafruit_BME280.h>
#include "settings.h"

unsigned long int temp1;

/* Configuración sensor de velocidad del viento */
unsigned int WindSpeed ;

/* Configuración sensor BME280 */
Adafruit_BME280 bme; // Objeto del sensor BME280

/* Configuración cliente WiFi */
WiFiClient espClient;

/* Configuración MQTT */
PubSubClient clientMqtt(espClient);
char msg[100]; // Aumentamos el tamaño del mensaje para acomodar los datos adicionales

void setup() {
  Serial.begin(9600);

  /* Iniciar wifi */
  setup_wifi();
  clientMqtt.setServer(mqtt_server, mqtt_port);
  clientMqtt.setCallback(callback);

  // Inicialización del sensor BME280
  if (!bme.begin(0x76)) {
    Serial.println("[ERROR] No se pudo inicializar el sensor BME280. Compruebe la conexión.");
    while (1); // Se queda atascado en un bucle infinito si no se puede inicializar el sensor
  }
}

void setup_wifi() {
  delay(10);

  // Comienza el proceso de conexión a la red WiFi
  Serial.println();
  Serial.print("[WIFI] Conectando a ");
  Serial.println(ssid);

  // Conexión a WiFi
  WiFi.begin(ssid, password);

  while (WiFi.status() != WL_CONNECTED) {
    delay(500);
    Serial.print(".");
  }

  Serial.println("");
  Serial.println("[WIFI] WiFi conectada");
  Serial.print("[WIFI] IP: ");
  Serial.print(WiFi.localIP());
  Serial.println("");
}

void callback(char* topic, byte* payload, unsigned int length) {
  Serial.print("[MQTT] Mensaje recibido (");
  Serial.print(topic);
  Serial.print(") ");
  String mqttcommand = "";
  for (int i = 0; i < length; i++) {
    mqttcommand += (char)payload[i];
  }
  Serial.print(mqttcommand);
  Serial.println();
  // Switch on the LED if an 1 was received as first character
  if (mqttcommand == "comando") {
    Serial.println("comando");
  }
}

void reconnect() {
  Serial.print("[MQTT] Intentando conectar a servidor MQTT... ");
  // Bucle hasta conseguir conexión
  while (!clientMqtt.connected()) {
    Serial.print(".");
    // Intento de conexión
    if (clientMqtt.connect(mqtt_id, mqtt_user, mqtt_password)) { // Ojo, para más de un dispositivo cambiar el nombre para evitar conflicto
      Serial.println("");
      Serial.println("[MQTT] Conectado al servidor MQTT");
      // Once connected, publish an announcement...
      clientMqtt.publish(mqtt_sub_topic_healthcheck, "starting");
      // ... and subscribe
      clientMqtt.subscribe(mqtt_sub_topic_operation);
    } else {
      Serial.print("[MQTT] Error, rc=");
      Serial.print(clientMqtt.state());
      Serial.println("[MQTT] Intentando conexión en 5 segundos");

      delay(5000);
    }
  }
}

void loop() {
  if (!clientMqtt.connected()) {
    reconnect();
  }
  clientMqtt.loop();

  if (millis()-temp1>update_time_sensors) {
    temp1=millis();

    // Lectura del puerto analógico y traducción del voltaje a velocidad
    WindSpeed = 6 * analogRead(A0) * (5.0 / 1023.0);

    // Lectura de datos del sensor BME280
    float temperature = bme.readTemperature();
    float humidity = bme.readHumidity();
    float pressure = bme.readPressure() / 100.0; // Convertir a hPa

    // Publicar la velocidad del viento en su propio tema MQTT
    snprintf (msg, 100, "%i m/s", WindSpeed);
    Serial.print("[MQTT] Enviando velocidad del viento: ");
    Serial.println(msg);
    clientMqtt.publish(mqtt_pub_topic_wind_speed, msg); // Publicar velocidad del viento

    // Publicar la temperatura en su propio tema MQTT
    snprintf (msg, 100, "%.2f °C", temperature);
    Serial.print("[MQTT] Enviando temperatura: ");
    Serial.println(msg);
    clientMqtt.publish(mqtt_pub_topic_temperature, msg); // Publicar temperatura

    // Publicar la humedad en su propio tema MQTT
    snprintf (msg, 100, "%.2f %%", humidity);
    Serial.print("[MQTT] Enviando humedad: ");
    Serial.println(msg);
    clientMqtt.publish(mqtt_pub_topic_humidity, msg); // Publicar humedad

    // Publicar la presión en su propio tema MQTT
    snprintf (msg, 100, "%.2f hPa", pressure);
    Serial.print("[MQTT] Enviando presión: ");
    Serial.println(msg);
    clientMqtt.publish(mqtt_pub_topic_pressure, msg); // Publicar presión

    delay (1000);
  }
}
```

Y settings.h:
```
// WiFi Configuration
const char* ssid = "Nombredetuwifi";
const char* password = "Contraseñadetuwifi";

// MQTT Configuration
const char* mqtt_server = "192.168.XX.XX";
const int mqtt_port = 1883;
const char* mqtt_user = "XXXXXX"; // Cambia "tu_usuario" por tu nombre de usuario MQTT
const char* mqtt_password = "XXXXXX"; // Cambia "tu_contraseña" por tu contraseña MQTT
const char* mqtt_id = "anemometer_cups";
const char* mqtt_sub_topic_healthcheck = "/home/meteo/healthcheck";
const char* mqtt_pub_topic_wind_speed = "/home/meteo/wind_speed";
const char* mqtt_pub_topic_temperature = "/home/meteo/temperature";
const char* mqtt_pub_topic_humidity = "/home/meteo/humidity";
const char* mqtt_pub_topic_pressure = "/home/meteo/pressure";
const char* mqtt_sub_topic_operation = "/home/meteo/operation";

// Other params
const int update_time_sensors = 30000;
```

Closed 2024-03-08.

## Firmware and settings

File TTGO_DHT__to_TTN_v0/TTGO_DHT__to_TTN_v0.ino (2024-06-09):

// ******************************************************************************************************************************************************************************************************************
// HACKATÓ PARK IoT - 16 de Març del 2.024
// FAB Casa del Mig (Sants / Barcelona)
// v0 (16/02/2.024)
// Maker: David Pérez
// ******************************************************************************************************************************************************************************************************************
//
// Tipus de dispositiu: Sensor de temperatura i humitat ambient
// Model: DHT22 (https://es.aliexpress.com/i/32883872442.html)

// Tensió alimentació (VCC): 3V3 a 5V DC
// Pins: #1 - VCC
//       #2 - Senyal
//       #3 - <buit>
//       #4 - GND 
//
// Datasheet: https://cdn-shop.adafruit.com/datasheets/DHT22.pdf
//
// Descripció del Codi:
// El següent codi mesura la temperatura i la humitat ambient amb el sensor DHT, les mostra pel Monitor Serial del IDE d'Arduino i les envia a la plataforma TTN (The Things Network) mitjantçant comunicació LoRa a 868 MHz.
//
// Placa: TTGO LoRa32 OLED 0,96" v1.0 (https://www.aliexpress.com/item/2pcs-of-TTGO-LORA32-868-915Mhz-SX1276-ESP32-Oled-display-Bluetooth-WIFI-Lora-development-board/32841743946.html)
//        TTGO LoRa32 OLED 0,96" v1.3 (https://es.aliexpress.com/item/4000628100802.html)
// Afegir la següent URL al gestor de plaques de la pestanya "Fitxer/Preferències": https://dl.espressif.com/dl/package_esp32_index.json del IDE de Arduino
// Descarregar el paquet "esp32 by Espressif Systems" ATENCIÓ IMPORTANT!!! la versió 1.0.6 al Gestor de plaques de la pestanya "Eines/Placa/Gestor de plaques" del IDE de Arduino
// Pinout: https://i0.wp.com/randomnerdtutorials.com/wp-content/uploads/2019/10/TTGO-LoRa-Board-Pinout.jpg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
// ATENCIÓ! Les versions d'aquesta placa diferents de la 1.x tenen errors interns de fabricació que es solucionen fent ponts en alguns pins. Buscar la solució a la xarxa.
//
// Connexions: 1) 5V (placa) - Vcc (breadboard)
//             2) Vcc (breadboard) - Pin #1 (DHT)
//             3) Pin #23 (placa) - Pin #2 (DHT)  
//             4) Resistència 4K7 entre Vcc(breadboard) i Pin #2 (DHT)
//             5) GND (placa) - Pin #4 (DHT) 
//
// Aquest codi requereix la biblioteca LMIC de Matthijs Kooijman (https://github.com/matthijskooijman/arduino-lmic)
// ******************************************************************************************************************************************************************************************************************


// Importem la llibreria que gestionarà el funcionament del sensor DHT
// #include <DHT.h>

// Importem la llibreria que ens permetrà comunicar-nos per I2C
#include <Wire.h>

// Cridem l'arxiu que conté dades necessaries per fer funcionar el codi principal
#include "config.h"

// Cridem l'arxiu necessari per guardar dades a la memòria de la placa quan s'utilitza el rellotge RTC
#include <rom/rtc.h>

// Declarem una variable que guarda el comptador de missatges que s'envien
// El comptador de missatges, emmagatzemat a la memòria RTC, es manté encara que utilitzem la funció "deep sleep"
RTC_DATA_ATTR uint32_t comptador = 0;


// -----------------------------------------------------------------------------------------------------------------------------------------------------------
// Funcions
// -----------------------------------------------------------------------------------------------------------------------------------------------------------

/* La funció “msb()” (big endian) transforma la variable float en un integer, per tant passem de 4 bytes a 2 bytes
   i després corre 8 bits el primer byte cap a la dreta per quedar-se solament amb aquest primer byte
   i fer desaparèixer el segon byte.
   Finalment es carrega el primer byte amb la instrucció “& 0xFF” per quedar-se solament amb un únic byte
*/
unsigned char msb(float value) {
  return (int(value) >> 8) & 0xFF;
}

/* La funció “lsb()” (little endian) transforma la variable float en un integer, per tant passem de 4 bytes a 2 bytes.
   Finalment es carrega el primer byte amb la instrucció “& 0xFF” per quedar-se solament amb el byte de la dreta.
*/
unsigned char lsb(float value) {
  return int(value) & 0xFF;
}


// Funció que envia el missatge a la plataforma TTN
void enviarMsg() {

  // Cridem les funcions que ens mesuren la temperatura i la humitat ambient i guardem el valor en una variable
  float temperatura = 22;
  float humitat = 33;

  // Comprovem si hi ha hagut algun error en la lectura (isnan = is not a number)
  if (isnan(temperatura) || isnan(humitat)) {
    Serial.println("Error obtenint les dades del sensor DHT22");
    return;
  }

  // https://www.quora.com/What-does-5-2f-means-in-C
  // %5.2fºC\n =
  // %: indica que comença a mostrar el valor que volem
  // 5: nº d'espais que ocuparà el valor a mostrar (ex. 23,05 = 5 espais)
  // 2: nº de decimals a mostrar
  // f: tipus de valor a mostrar (f: float, d: decimal)
  // ºC: text que es mostrarà després del valor mostrat
  // \n: salt de linia
  // NOTA: Perque surti el caracter "%" després del valor a mostrar hem d'escriure "%%"

  // Mostrem pel Monitor Serial el comptador del paquet que enviarem i les mesures realitzades de temperatura, humitat ambient, pressió baromètica i alçada

  // ATENCIÓ!!! La funció "printf" NO és compatible amb una placa d'ARDUINO, solament amb plaques ESP32,
  // S'utilitza per simplificar en una sola linia de codi el text i el valor que volem mostrar.
  // Si es vol utilitzar amb plaques Arduino s'ha de baixar la llibreria adequada.

  Serial.println("");
  Serial.printf("[SNS] Comptador: %d\n", comptador);
  Serial.printf("[SNS] Temperatura: %4.1fºC\n", temperatura);
  Serial.printf("[SNS] Humitat: %d%%\n", (int) humitat);
  Serial.println("");

  // Declarem i inicialitzem una variable que enmagatzemarà la longitud màxima que tindrà la cadena de caracters del missatge a enviar.
  // IMPORTANT! S'ha de declarar com una constant per poder utilizar-la en un array
  const int Tamany_Buffer_Msg = 64;

  // Declarem i inicialitzem la variable array de tipus "char" que enmagatzemarà la càrrega útil (payload) dels missatges a enviar al display OLED
  char buffer[Tamany_Buffer_Msg];

  // Enpaquetem dins la variable el missatge que enviarem al display OLED
  snprintf(buffer, sizeof(buffer), "[TTN] Enviant msg #%03d\n", (byte) (comptador & 0xFF));

  // Mostrem pel display OLED el comptador del missatge que estem enviant
  screenPrint(buffer);

  /*
    Les dades que enviarem a la plataforma TTN les codificarem d'aquesta manera:

    Hem de tenir em compte que si enviem un número comprés entre 0 i 255 utilitzarem un sol byte però que si el número està comprés entre 256 i 65.535 aleshores
    necessitarem 2 bytes, i a més a més aquests valors han de ser sempre positius, mai negatius.
    Si tenim un número amb decimals, aleshores hem de multiplicar per 100 per eliminar els decimals i convertir el valor en un número enter.
    Exemple: 23,58 -> 23,58 * 100 = 2358 > 255 -> 2 bytes

    Si volem enviar un número negatiu amb decimals hem de sumar-li un valor suficient per tal que quedi positiu i després multiplicar per 100 com s'ha explicat abans
    Exemple: -62,98 -> (-62,98 + 100) * 100 = 3702 > 255 -> 2 bytes
            -58 -> -58 + 100 = 42 < 255 -> 1 byte

    comptador (1 byte)
    MSB (temperatura + 40)*100 (1 byte)       (*)
    LSB (temperatura + 40)*100 (1 byte)       (*)
    humitat (1 byte)

    (*) El valor 40 és perque segons el datasheet del sensor de temperatura DHT (https://cdn-shop.adafruit.com/datasheets/DHT22.pdf)
    el rang de temperatures que pot mesurar està comprés entre -40 i 125ºC.
    Si sumem aquest valor a sigui quina sigui la mesura evitem que surti un valor negatiu

    La funció descodificadora dels missatges "Uplink" que hem enviat a la plataforma TTN s'ha d'anomenar SEMPRE "Decoder"
    i ha d'estar escrita en llenguatge Javascript!!!):

    function Decoder(bytes, port) {
    var descodificar = {};
    if (port == 20) {
     descodificar.comptador = bytes[0];
     descodificar.temperatura = (bytes[1] * 256 + bytes[2]) / 100.0 - 40.0;
     descodificar.humitat = bytes[3];
    }
    return descodificar;
    }
  */

  // Reescalem les mesures preses pel sensor per encapsular-les dins d'una variable del tipus array
  temperatura = (temperatura + 40.0) * 100;

  // Declarem una variable que guardarà el nombre d'elements (bytes) que volem enviar a la plataforma de TTN. IMPORTANT! S'ha de declarar com una constant
  // per poder utilizar-la com una variable del tipus array
  const byte numElements = 4;

  // Declarem una variable del tipus array on guardarem el comptador i totes les dades mesurades pel sensor DHT
  byte data[numElements] = {
    (byte) (comptador & 0xFF),
    msb(temperatura), lsb(temperatura),
    lsb(humitat),
  };

  // Enviem el paquet de dades a la plataforma TTN
#if LORAWAN_CONFIRMED_EVERY
  bool confirmed = (count % LORAWAN_CONFIRMED_EVERY == 0);
#else
  bool confirmed = false;
#endif
  ttn_send(data, sizeof(data), port_LORAWAN, confirmed);

  // Incrementem en una unitat el valor de comptador de missatges enviats
  comptador++;
}

// Funció que gestiona la connexió del microcontrolador amb la plataforma TTN
void callback(byte message) {

  if (EV_JOINING == message) screenPrint("[TTN] Connectant-se...\n");
  if (EV_JOINED == message) screenPrint("[TTN] Connectat!\n");
  if (EV_JOIN_FAILED == message) screenPrint("[TTN] Connexió fallida\n");
  if (EV_REJOIN_FAILED == message) screenPrint("[TTN] Reconnexió fallida\n");
  if (EV_RESET == message) screenPrint("[TTN] Reset\n");
  if (EV_LINK_DEAD == message) screenPrint("[TTN] Enllaç mort\n");
  if (EV_ACK == message) screenPrint("[TTN] ACK rebut\n");
  if (EV_PENDING == message) screenPrint("[TTN] Missatge descartat\n");
  //if (EV_QUEUED == message) screenPrint("[TTN] Missatge en cua\n");

  if (EV_TXCOMPLETE == message) {
    screenPrint("[TTN] Missatge enviat\n");
  }

  if (EV_RESPONSE == message) {

    screenPrint("[TTN] Resposta: ");

    size_t len = ttn_response_len();
    uint8_t data[len];
    ttn_response(data, len);

    char buffer[6];
    for (byte i = 0; i < len; i++) {
      snprintf(buffer, sizeof(buffer), "0x%02X ", data[i]);
      screenPrint(buffer);
    }
    screenPrint("\n");
  }
}


void setup() {
  // Inicialització del Monitor Serial
#ifdef DEBUG_PORT
  DEBUG_PORT.begin(velocitatTransmissio);
#endif

  // Configurem el pin de dades on tenim connectat el sensor DHT com una "entrada"
//  pinMode(pinDHT, INPUT);

  // Cridem la funció que ens gestionarà el funcionament del display OLED
  screenSetup();

  // Mostrem un missatge de presentació per la pantalla del display OLED
//  screenPrint("SENSOR DHT\n");

  // Test I2C
  //i2cSetup();                             // El comentem perque ja inicialitzem la comunicació I2C quan també inicialitzem el sensor DHT
  //i2cScan();

  // Cridem la funció que ens gestionarà funcionament del sensor DHT
 // sensorSetup();

  // Esperem un temps per poder veure el missatge de benvinguda al display OLED de la placa
  delay(2000);

  // Cridem la funció que ens gestionarà el mòdul LoRa de la placa
  if (!ttn_setup()) {
    screenPrint("No s'ha pogut trobar el mòdul de ràdio!\n");
    while (true);
  }

  // Cridem les funcions que ens permetran connectar-nos a la plataforma TTN
  ttn_register(callback);
  ttn_join();
  ttn_sf(LORAWAN_SF);
  ttn_adr(LORAWAN_ADR);
}


void loop() {
  // Enviem el missatge cada cert interval de temps
  static long ultimMsg = 0;
  if (0 == ultimMsg || millis() - ultimMsg > tempsEnviamentMsg) {

    // Cridem la funció que envia els missatges a la plataforma TTN
    enviarMsg();

    // Resetegem el temps a 0
    ultimMsg = millis();
  }

  // IMPORTANT!!! Cridar aquesta funció SEMPRE que volguem enviar dades a la plataforma TTN a la funció "loop" del codi principal
  ttn_loop();
}

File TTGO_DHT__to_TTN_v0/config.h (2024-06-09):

// ------------------------------------------------------------------------------------------------------------------
// ARXIU DE CONFIGURACIÓ
// ------------------------------------------------------------------------------------------------------------------

#pragma once

#include <Arduino.h>
#include <lmic.h>

// Configurar "credentials.h" amb la configuració del nostre node
#include "credentials.h"

void ttn_register(void (*callback)(uint8_t message));

// -----------------------------------------------------------------------------
// Configuració
// -----------------------------------------------------------------------------

#define DEBUG_PORT              Serial
int velocitatTransmissio = 115200;          // Velocitat de transmissió del Monitor Serial (en bauds/seg)
int tempsEnviamentMsg = 60000;              // Envia missatges cada interval de temps (en millis)
byte port_LORAWAN = 20;                     // Port de la plataforma TTN on s'enviaran els missatges
byte LORAWAN_CONFIRMED_EVERY = 0;           // Envia un missatge de confirmat a tots aquests missatges (0 significa mai)
unsigned char LORAWAN_SF = DR_SF7;          // Spreading factor (Factor de propagació)
byte LORAWAN_ADR = 0;                       // Activa l'ADR

// -----------------------------------------------------------------------------
// DEBUG
// -----------------------------------------------------------------------------

#ifdef DEBUG_PORT
#define DEBUG_MSG(...) DEBUG_PORT.printf( __VA_ARGS__ )
#else
#define DEBUG_MSG(...)
#endif

// -----------------------------------------------------------------------------
// Missatges personalitzats
// -----------------------------------------------------------------------------

byte EV_QUEUED = 100;
byte EV_PENDING = 101;
byte EV_ACK = 102;
byte EV_RESPONSE = 103;

// -----------------------------------------------------------------------------
// Hardware
// https://www.thethingsnetwork.org/forum/t/big-esp32-sx127x-topic-part-2/11973
// -----------------------------------------------------------------------------

// Pins connexions SPI per connectar amb el mòdul LoRa (SPI)
const byte SCK_GPIO = 5;
const byte MISO_GPIO = 19;
const byte MOSI_GPIO = 27;
const byte NSS_GPIO = 18;
const byte RESET_GPIO = 14;
const byte DIO0_GPIO = 26;
const byte DIO1_GPIO = 33;
const byte DIO2_GPIO = 32;


// ------------------------------------------------------------------------------------------------------------------
// Display OLED (I2C)
// ------------------------------------------------------------------------------------------------------------------

const byte pinSDA = 4;
const byte pinSCL = 15;
const byte pinRESET_I2C = 16;


// -----------------------------------------------------------------------------
// LEDs
// -----------------------------------------------------------------------------
const byte pinLed = 2;

// ------------------------------------------------------------------------------------------------------------------
// Sensor DHT  
// ------------------------------------------------------------------------------------------------------------------

// Declarem una variable on guardarem el pin on es connectarà el sensor DHT22
// const byte pinDHT = 23;

// Especifiquem el tipus de sensor (DHT11 o DHT22)
// #define DHTTYPE DHT22

// Creem un objecte de la clase DHT
//DHT dht(pinDHT, DHTTYPE);

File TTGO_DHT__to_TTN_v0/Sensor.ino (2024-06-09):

// ------------------------------------------------------------------------------------------------------------------
// Sensor DHT
// ------------------------------------------------------------------------------------------------------------------

// Llibreries
//#include "DHT.h"

// Funció que ens inicialitza el sensor DHT
//void sensorSetup() {
//  dht.begin();
//}

// Funció que ens mesura la temperatutra amb el sensor DHT22
//float temperaturaDHT22() {
//  return dht.readTemperature();
//}

// Funció que ens mesura la humitat ambient amb el sensor DHT22
//float humitatDHT22() {
//  return dht.readHumidity();
//}
